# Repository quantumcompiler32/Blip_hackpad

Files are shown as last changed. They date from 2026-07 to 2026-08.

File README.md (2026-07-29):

# Blip

Blip is a custom macropad I am designing for macOS. It combines a 4-row by
3-column mechanical-key matrix, two rotary encoders, a XIAO ESP32-S3, and two
displays. The goal is to make a small physical control surface that can trigger
useful actions and show status without feeling like a tiny touchscreen.

## Features

- 12-key (3x4) mechanical switch matrix
- 1N4148 diode matrix for anti-ghosting
- Seeed Studio XIAO ESP32-S3 controller for native USB HID
- MCP23017 I2C GPIO expander for additional IO
- Newhaven 20x4 character OLED display
- Two rotary encoders with push switches
- USB-C-only power through the removable XIAO module
- A removable MCP23017 GPIO expander and removable display connections

## Bill of materials

The full, quoted CSV is in [`BOM/Hackpad_final_BOM.csv`](./BOM/Hackpad_final_BOM.csv).
It matches the current PCB: 12 keys, 12 diodes, two encoders, two 4.7 kΩ
pull-ups, one 100 nF capacitor, the XIAO ESP32-S3, the MCP23017, and both
display modules. The removable socket and header parts are listed separately
because they are assembly parts rather than separate KiCad footprints.

The current component total is **$97.95 USD** using the listed prices. That
number does not include PCB fabrication, an enclosure, keycaps, encoder knobs,
or mounting hardware. Prices are planning numbers, not a final purchase quote.

## Repository Structure

```text
Blip_hackpad/
├── BOM/                Bill of materials
├── Images/             Schematic and PCB reference images
├── PCB/                KiCad design files and manufacturing outputs
├── docs/               Architecture, specifications, and validation evidence
├── src/
│   ├── blip-agent/     Background host event pipeline
│   ├── control-center/ Minimal diagnostic view
│   ├── firmware/       Complete PlatformIO project
│   ├── shared/         Device-event and semantic-state contracts
│   └── simulator/      Virtual Blip Device and scenario CLI
└── test/               Foundation acceptance tests
```

## Hardware submission status

The KiCad project in `PCB/` is the hardware source of truth. Automated ERC,
DRC, schematic-parity, source-policy, and BOM checks are recorded in
`docs/hardware/`. The Hardware Validation Gate is not a manufacturing approval:
I still need to inspect the current STEP export, confirm connector and encoder
clearances with the real parts, review USB-C access, and sign the final
manufacturing checklist in [`docs/hardware/hardware-change-guide.md`](./docs/hardware/hardware-change-guide.md).
The complete repository-versus-Macondo checklist is in
[`docs/hardware/macondo-submission-checklist.md`](./docs/hardware/macondo-submission-checklist.md).

To rerun the repository checks:

```sh
sh scripts/verify-hardware-source-of-truth.sh
sh scripts/verify-minimal-pcb-corrections.sh
sh scripts/verify-bom-against-pcb.sh
sh scripts/verify-hardware-validation-gate.sh
```

## Simulator tracer scenario

Node.js 22.6 or newer can run the Foundation tracer without installing
dependencies:

```sh
npm test
npm run --silent scenario
npm run --silent scenario:view > /tmp/blip-control-center-diagnostic.html
```

The scenario command emits machine-readable JSON. The HTML command renders the
same Agent observation as a minimal Control Center diagnostic view. Both outputs
label the device as virtual, and the scenario never executes a host action.

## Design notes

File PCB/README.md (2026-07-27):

# Blip PCB source of truth

The three `Hackpad.kicad_*` files in this directory are the authoritative revision-one KiCad project. They were migrated unchanged from Moksh's active project on 2026-07-18.

Do not commit KiCad locks, automatic backups, local preferences, history folders, cached footprint data, or the unrelated Starter project. Hardware corrections must be made to these sources and documented in the Hardware Change Guide.

Run `sh scripts/verify-hardware-source-of-truth.sh` to verify the durable source policy. The migration hashes are historical evidence in the baseline findings; they are intentionally not enforced after approved PCB edits. A passing source-policy check does not mean the Hardware Validation Gate has passed.

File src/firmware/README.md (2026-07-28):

# Blip firmware

This folder is a self-contained PlatformIO project under the repository's
authoritative `src/` source root. Firmware files are in this project's `src/`,
headers are in `include/`, and the build configuration is `platformio.ini`.

## Controls

- Left/volume encoder: rotate for volume, press for mute.
- Right/profile encoder: rotate through three profiles, press to save/select.
- The macropad communicates and receives configuration only through USB.

Key actions and profile names are saved in ESP32 flash and can be changed over
USB serial without rebuilding the firmware. Wi-Fi and Bluetooth are disabled.

## Build and flash

1. Install [Visual Studio Code](https://code.visualstudio.com/) and the
   PlatformIO extension.
2. Open the repository's `src/firmware` folder as the PlatformIO project.
3. Connect the XIAO ESP32-S3 by USB.
4. Run **PlatformIO: Upload**.
5. Open the serial monitor at 115200 baud for diagnostics.

Command-line users can run:

```sh
cd src/firmware
pio run
pio run --target upload
pio device monitor
```

## Hardware requirements and limitations

- Newhaven pin 16 (`/RES`) must be pulled up to 3.3 V. The current schematic
  ties it to ground, which permanently resets the display.
- Newhaven pin 4 (`SA0`) must be tied to 3.3 V, selecting address `0x3D`.
  The 128x64 module remains at `0x3C`. Two devices at the same I2C address
  cannot be separated by firmware or by automatic address detection.
- This firmware requires a XIAO ESP32-S3 for native USB HID support.

## Serial commands

- `status` — rerun the I2C and peripheral report
- `config` — print the stored JSON configuration
- `set-config <JSON>` — validate and save a complete configuration
- `reset-config` — restore the example profiles
- `reboot` — restart the controller

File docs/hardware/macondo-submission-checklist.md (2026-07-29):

# Macondo submission checklist

This is the checklist I use before submitting Blip to Macondo. It separates the
repository work from the parts that need my own hands, photos, and decisions.

## Repository package

- [x] `PCB/` contains the authoritative KiCad project: schematic, board, and project file.
- [x] `BOM/Hackpad_final_BOM.csv` is valid CSV and matches the populated PCB references and footprint counts.
- [x] `src/firmware/` contains the PlatformIO firmware project.
- [x] `src/` contains the simulator and the shared device-event boundary.
- [x] `CAD/Blip-PCB-Assembly.step` is included as mechanical evidence.
- [x] `docs/hardware/` contains the pin-map contract, hardware-change guide, validation reports, and research notes.
- [x] The root README explains what Blip is, how the repository is organized, how to run the simulator, and what the current hardware status means.
- [x] The repository checks pass locally.

Run these from the repository root:

```sh
sh scripts/verify-hardware-source-of-truth.sh
sh scripts/verify-minimal-pcb-corrections.sh
sh scripts/verify-bom-against-pcb.sh
sh scripts/verify-hardware-validation-gate.sh
npm test
```

## Before I submit the hardware design for review

- [ ] Commit the final README, BOM, and verification-script changes.
- [ ] Push the commit to `main` and open the GitHub repository link in a private browser window.
- [ ] Open the KiCad project from a clean clone and confirm the schematic and PCB load without missing libraries.
- [ ] Open the current STEP export and check the board outline, mounting holes, USB-C access, display clearance, and encoder clearance.
- [ ] Confirm that the listed parts and prices still match the parts I intend to order.
- [ ] Make sure the Macondo project title and description describe the current two-display design, not an older one-screen version.

## Before I call the hardware project shipped

- [ ] Order or otherwise obtain the parts.
- [ ] Assemble the board or first article and take clear photos of the real hardware.
- [ ] Test the USB-C connection, matrix, both encoders, both displays, and the controller.
- [ ] Add honest journal entries on the Macondo project page with my own notes, photos, and what went wrong or changed.
- [ ] Complete and sign the final manufacturing checklist in `hardware-change-guide.md`.

The automated checks prove that the repository is internally consistent. They do
not prove that a real part fits, that the board has been manufactured, or that a
physical control feels right. Those are my checks to complete and document.

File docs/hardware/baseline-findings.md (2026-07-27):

# Hardware baseline findings

Recorded 2026-07-18. The Hardware Validation Gate has **not passed**. This is a preservation audit, not manufacturing approval.

## Preserved sources

| File | SHA-256 |
| --- | --- |
| `Hackpad.kicad_pro` | `d8c1aa42e53af8127d99fc2cb34fe868f9aad859bb383313cd3f733fd328e3e2` |
| `Hackpad.kicad_sch` | `2a603a45c626644701ca69ce53ecbd3906184bcae56ee97f0529a81a8c31a7d6` |
| `Hackpad.kicad_pcb` | `38016ccee050912f7b6a07835543e346bc84e0e7174babc7ce56f270c00cc676` |

The hashes match Moksh's active external project at migration time, proving that ticket 01 did not alter placement, routing, or matrix topology. They are immutable migration evidence, not a permanent test of the editable authoritative sources.

## Baseline observations

- Controller mismatch: the schematic embeds `XIAO_RP2040:MOUDLE-SEEEDUINO-XIAO`, exposes SAMD-style `PA...` pin names, and assigns `RF_Module:MCU_Seeed_ESP32C3`. The BOM and firmware require XIAO ESP32-S3. Ticket 02 must replace and verify this identity without moving the header pads.
- ERC evidence supplied before migration showed zero errors and three warnings: GND/VSS aliasing on the Newhaven display, missing XIAO symbol library, and an unattached no-connect flag. Four tests were ignored. Each warning and exclusion still needs resolution or justification.
- DRC evidence supplied before migration showed zero violations and zero unconnected items, but schematic parity was not run and five tests were ignored. A green DRC screenshot alone is not a gate pass.
- The board preserves the 4×3 matrix, two encoders, MCP23017, two I2C displays, and USB-powered XIAO header arrangement expected by the product contract.
- BOM controller text says XIAO ESP32-S3 but lists an ESP32-C3 footprint. Socket/header items and mechanical installed heights still require audit.
- KiCad CLI is not available in the current shell, so ERC, DRC, parity, and fresh mechanical export were not rerun in this ticket.

## Gate state

| Check | Baseline state |
| --- | --- |
| Authoritative source migration | Passed by matching hashes |
| Routed placement preservation | Passed by byte-identical PCB source |
| XIAO ESP32-S3 identity | Failed; correction required |
| Firmware/header-position agreement | Passed against Seeed's official D0–D10 to GPIO map |
| ERC | Not passed; warnings/exclusions open |
| DRC | Not passed for the gate; prior clean result has exclusions |
| Schematic-to-PCB parity | Not run |
| BOM/socket consistency | Not passed |
| Current budget and pull-up calculation | Not performed |
| Mechanical review and fresh STEP | Not performed |
| Human manufacturing approval | Not granted |

Ticket 02 applied the smallest evidence-backed controller, socket, power, and Newhaven I2C corrections while preserving the matrix, component placement, and existing routed nets. U1's two rows moved inward 0.88 mm to match Seeed's official 15.24 mm spacing. The baseline hashes above remain migration evidence only. Fresh DRC/parity, mechanical review, and human approval remain ticket-03 gate work.

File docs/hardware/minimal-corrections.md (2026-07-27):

# Ticket 02 minimal hardware corrections

Applied 2026-07-18. This records edits, not manufacturing approval. Primary-source electrical evidence is in [component research](component-research.md).

## Controller and assembly

- U1 now identifies only the Seeed Studio XIAO ESP32-S3 in the schematic, PCB, BOM, and firmware-facing pin contract.
- U1 now uses Seeed's official seven-by-two center pattern: 2.54 mm contact pitch and 15.24 mm row spacing, rotated into the existing board orientation. Correcting the old 17.0 mm spacing moved each row inward 0.88 mm. The existing route endpoints remain inside the 2.2 mm carrier pads, so no functional net or matrix route needed to move.
- The obsolete ESP32-C3 underside land pattern and 3D-model reference were removed. U1 5V/VBUS remains intentionally unconnected; the XIAO USB-C connector is the only power input.
- The BOM now includes exact XIAO male/female header parts, an exact 0.3-inch MCP23017 DIP socket, and exact Samtec male/female 2.54 mm connector pairs for both displays. Installed-height, enclosure, and hand-access validation remain part of the ticket-03 mechanical review.

## Newhaven display

The Newhaven NHD-0420CW-AB3 is corrected to the manufacturer's 3.3 V I2C wiring:

| Pins | Applied net | Reason |
| --- | --- | --- |
| 1, 3, 5, 6, 10–15, 17, 19, 20 | GND | VSS, REGVDD, I2C-mode NC, and BS0/BS2 requirements |
| 2, 4, 18 | 3.3 V | VDD, SA0 high, and BS1 high |
| 7 | SCL | Shared I2C clock |
| 8–9 | SDA | Required tied SDAIN/SDAOUT |
| 16 | Direct 3.3 V | Active-low reset held inactive; removes the baseline R3 part that had no PCB footprint |

SA0 high selects seven-bit address `0x3D`, leaving the fixed graphical module at `0x3C` and MCP23017 at `0x20`. New display straps use short B.Cu segments beside the existing header row; no matrix trace, switch, encoder, or component origin moved. The only U1 geometry change is the documented 0.88 mm inward movement of each header row.

## Power, pull-ups, and decoupling

- Seeed documents up to 700 mA from 3V3. The researched **external-load subtotal** is 170.8 mA. It excludes the XIAO's CPU/radio peak, regulator thermal behavior, and USB source/cable, so the worst-case current-budget criterion remains open for ticket 03.
- R1/R2 remain 4.7 kΩ. The exact graphical module has onboard 4.7 kΩ pull-ups, producing about 2.35 kΩ effective resistance and about 1.4 mA sink per low bus line. Keeping carrier pull-ups avoids making repairability depend on the graphical module.
- C1 is the existing 100 nF local rail bypass beside the MCP23017/controller area. Both display assemblies are manufacturer modules rather than bare OLED panels. No speculative bulk capacitor or display-module redesign was added; maximum-brightness, Wi-Fi, rail-noise, and I2C-rise-time measurements remain required at the Hardware Validation Gate.

## Verification still required

KiCad 10.0.1 is installed inside the macOS app bundle. Ticket-02 verification produced:

- ERC: 0 errors and 0 warnings; four project checks remain intentionally ignored and require ticket-03 disposition.
- PCB Editor DRC before the final official XIAO row-spacing correction showed 0 violations and 0 unconnected items; five checks remained ignored. The post-correction CLI DRC still aborts with exit 134, so a fresh GUI DRC is explicitly required by ticket 03.
- Schematic parity: not passed. KiCad continued to retain a stale `Missing footprint R3` marker after R3 was removed in favor of direct reset-high wiring, and the CLI DRC process aborted with exit 134 before writing a report. Ticket 03 must clear/rebuild the project cache and rerun parity from a fresh session.

Ticket 03 must also inspect the new B.Cu display straps, verify pin-one/USB/display orientation and installed heights, export a fresh STEP model, and capture the human visual approval. Do not manufacture from ticket 02 alone.

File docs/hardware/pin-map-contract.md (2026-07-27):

# Blip revision-one pin-map contract

Status: **ticket-02 electrical contract applied; fresh KiCad gate verification remains required**.

The required Blip Controller is the Seeed Studio XIAO ESP32-S3. Header-to-GPIO identities come from Seeed Studio's official XIAO ESP32-S3 pin map: <https://wiki.seeedstudio.com/xiao_esp32s3_getting_started/>. Ticket 02 replaced the obsolete controller identities with an embedded ESP32-S3 symbol and a 14-contact, 2.54 mm through-hole socket footprint. The official 15.24 mm row spacing moved each baseline row inward 0.88 mm; functional nets and their route endpoints were preserved.

| XIAO header | ESP32-S3 GPIO | Board net | Blip role | Contract state |
| --- | --- | --- | --- | --- |
| D0 | GPIO1 | `ENC_C` | Left encoder A | Agreed; later net name `LEFT_ENC_A` |
| D1 | GPIO2 | `ENC_D` | Left encoder B | Agreed; later net name `LEFT_ENC_B` |
| D2 | GPIO3 | `ENC_SW1` | Left encoder press | Agreed; later net name `LEFT_ENC_SW` |
| D3 | GPIO4 | Unconnected | Reserved | Intentionally unused; no-connect disposition remains to verify |
| D4 | GPIO5 | `SDA` | Shared I2C data | Agreed by PCB, firmware, and Seeed pin map |
| D5 | GPIO6 | `SCL` | Shared I2C clock | Agreed by PCB, firmware, and Seeed pin map |
| D6 | GPIO43 | Unconnected | Reserved UART TX | Intentionally unused |
| D7 | GPIO44 | Unconnected | Reserved UART RX | Intentionally unused |
| D8 | GPIO7 | `ENC_SW` | Right encoder press | Agreed; later net name `RIGHT_ENC_SW` |
| D9 | GPIO8 | `ENC_A` | Right encoder A | Agreed; later net name `RIGHT_ENC_A` |
| D10 | GPIO9 | `ENC_B` | Right encoder B | Agreed; later net name `RIGHT_ENC_B` |
| 3V3 | 3V3_OUT | `+3.3V` | Logic and display supply | Agreed; preliminary external maximum is 170.8 mA |
| GND | GND | `GND` | Common return | Agreed |
| 5V | VBUS | Unconnected | Not used | Required by USB-C-only power decision |

## MCP23017 matrix contract

The expander is on the shared I2C bus at `0x20`, with address pins A0–A2 grounded. GPA0–GPA3 drive `ROW0`–`ROW3`; GPB0–GPB2 read `COL0`–`COL2`. Firmware currently configures ports 0–3 as row outputs and ports 8–10 as pulled-up column inputs. The twelve switch/diode positions remain a 4×3 matrix.

## Display contract

| Component | Address | Supply | Bus role | Baseline status |
| --- | --- | --- | --- | --- |
| MCP23017 | `0x20` | 3.3 V | Matrix GPIO | A0–A2 grounded; address agrees |
| DM-OLED096-636 | `0x3C` | 3.3 V | Persistent Status | Manufacturer-default fixed address verified |
| NHD-0420CW-AB3 | `0x3D` | 3.3 V | Contextual Status | SA0 tied to 3.3 V; address agrees |

The graphical OLED connector is GND, 3.3 V, SCL, SDA on pins 1–4. Its module includes 4.7 kΩ pull-ups; together with R1/R2 this gives about 2.35 kΩ effective pull-up resistance. The Newhaven now connects VSS pins 1/20 to GND, VDD pin 2 to 3.3 V, REGVDD pin 3 to GND, SA0 pin 4 to 3.3 V, I2C NC pins 5–6 and 10–15 to GND, pin 7 to SCL, pins 8/9 together to SDA, /RES pin 16 directly to 3.3 V, BS0/BS2 pins 17/19 to GND, and BS1 pin 18 to 3.3 V. This selects 3.3 V I2C operation and address `0x3D`. Direct reset-high replaced the baseline R3 pull-up because R3 had no PCB footprint and no controlled reset is required.

The preliminary maximum external 3.3 V load is 170.8 mA: 135 mA Newhaven, 32 mA graphical OLED, 1 mA MCP23017, and 2.8 mA with both I2C lines low through the effective pull-ups. See [component research](component-research.md) for primary sources and limitations. The 700 mA Seeed regulator-output statement leaves nominal margin, but radio/CPU peaks, thermal behavior, bus rise time, display brightness, and assembled measurements remain Hardware Validation Gate checks.

USB-C on the XIAO is the only power input and carries USB HID plus serial. No project path, secret, or host configuration crosses this hardware contract.

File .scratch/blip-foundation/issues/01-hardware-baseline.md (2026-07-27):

# 01 — Establish the authoritative Blip hardware baseline

**What to build:** Preserve the active KiCad project as Blip's single hardware source of truth and produce one reviewed XIAO ESP32-S3 pin-map contract covering every hardware and firmware connection.

**Blocked by:** None — can start immediately.

**Status:** ready-for-agent

- [ ] Only the active KiCad sources are authoritative; generated history, locks, preferences, and unrelated projects are excluded.
- [ ] Existing placement, routing, and matrix topology are preserved.
- [ ] One pin-map contract records the agreed controller target and every observed agreement or mismatch across inputs, displays, I2C, USB, power, firmware, and KiCad.
- [ ] Baseline ERC, DRC, parity, BOM, and mechanical findings are recorded without claiming the gate passed.

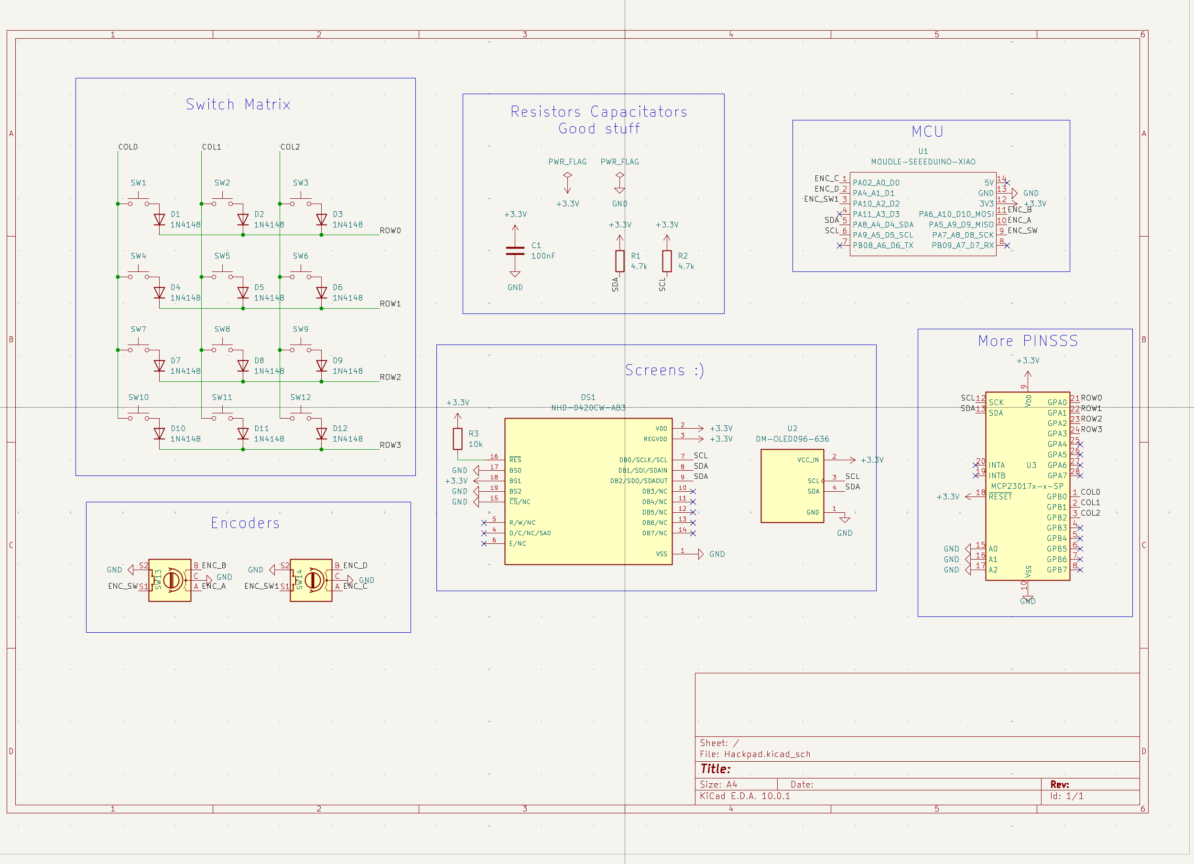
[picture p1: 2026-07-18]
Images/PCBSchematic.png

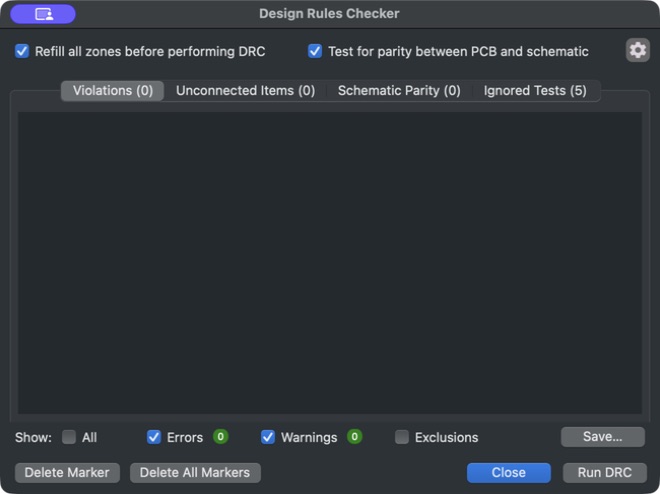
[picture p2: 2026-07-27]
docs/hardware/evidence/drc-parity.png

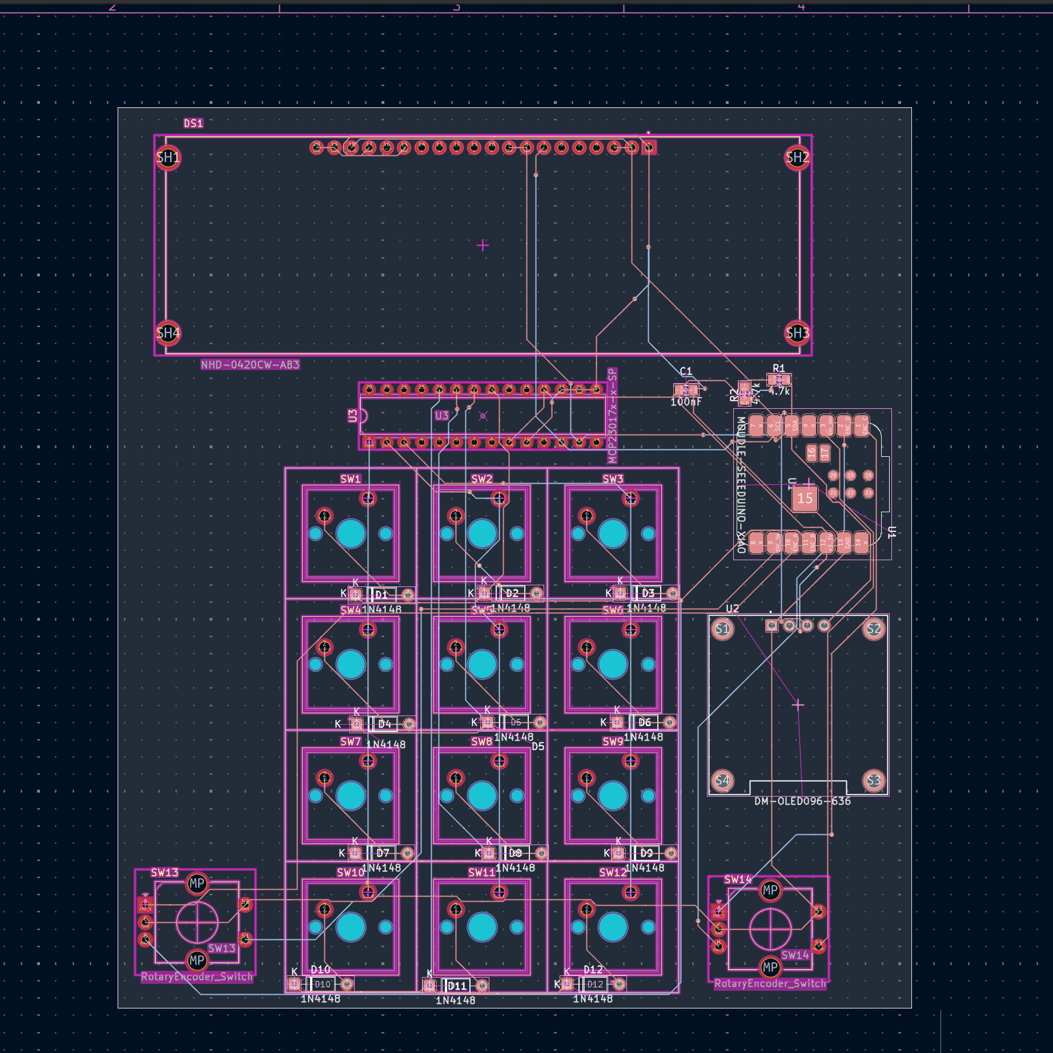
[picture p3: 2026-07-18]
Images/PCBFront.png

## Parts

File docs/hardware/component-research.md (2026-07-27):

# Component research for minimal PCB corrections

This note records only first-party manufacturer facts needed by ticket 02. It is not a substitute for a fresh ERC, DRC, schematic/PCB parity check, assembled-board test, or human manufacturing approval.

## Decision summary

| Part | Evidence-backed ticket 02 constraint |
| --- | --- |
| Seeed Studio XIAO ESP32-S3 | Use the official XIAO ESP32-S3 symbol/footprint and its 14 castellated/header pins. D4/GPIO5 is SDA, D5/GPIO6 is SCL, and 3V3 is a regulated output rated by Seeed for 700 mA. Keep 5V/VBUS unconnected on the carrier for the locked USB-C-only design. |
| Newhaven NHD-0420CW-AB3 | In I2C mode it is 3.3 V only: VDD=3.3 V and REGVDD=0 V. Tie SDAIN and SDAOUT together, set BS0=0, BS1=1, BS2=0, and use SA0 high to select 7-bit address `0x3D`. |
| DisplayModule DM-OLED096-636 | The four-pin breakout is GND, VCC_IN, SCL, SDA and accepts 2.8–5.5 V at VCC_IN. Its documented default control byte `0x78` is 7-bit address `0x3C`. The module schematic already includes 4.7 kΩ I2C pull-ups. |
| Microchip MCP23017 | Operates from 1.8–5.5 V, draws at most 1 mA under the specified 1 MHz condition, and uses 7-bit address `0100 A2 A1 A0`; biasing A2:A0 low selects `0x20`. A0:A2 and RESET must not float. |

## Seeed Studio XIAO ESP32-S3

- The standard board is **21 mm × 17.8 mm**. Seeed publishes the authoritative DXF, KiCad project, symbol library, footprint library, and 3D model from the product wiki. The PCB should import/use those official assets instead of retaining the current ESP32-C3 footprint or the SAMD-style symbol. [Seeed XIAO ESP32-S3 hardware overview and resources](https://wiki.seeedstudio.com/xiao_esp32s3_getting_started/)
- The official header mapping relevant to Blip is: D0=GPIO1, D1=GPIO2, D2=GPIO3, D4/SDA=GPIO5, D5/SCL=GPIO6, D8=GPIO7, D9=GPIO8, and D10=GPIO9. The same page identifies 5V as VBUS, 3V3 as `3V3_OUT`, and GND as ground. [Seeed pin map](https://wiki.seeedstudio.com/xiao_esp32s3_getting_started/#xiao-esp32-s3-front)
- Seeed describes the 3V3 pin as the onboard regulator's output and says **700 mA may be drawn**. It describes the 5V pin as USB-port output and warns that external input on that pin requires a diode. Blip does not use external 5V injection, so the carrier's 5V/VBUS header pin should remain unconnected. [Seeed power-pin guidance](https://wiki.seeedstudio.com/xiao_esp32s3_getting_started/#power-pins)
- Seeed lists typical standard-board consumption as **5 V at 19 mA** during its unspecified baseline operating condition. This is not a radio-transmit peak and must not be used as a worst-case ESP32-S3 current figure. [Seeed specifications](https://wiki.seeedstudio.com/xiao_esp32s3_getting_started/#specification)
- The module is supplied without headers by default; Seeed instructs the user to solder headers for expansion-board use. A socketed Blip assembly therefore requires explicit matching 2.54 mm header/socket BOM items rather than assuming they ship with the XIAO. [Seeed solder-header guidance](https://wiki.seeedstudio.com/xiao_esp32s3_getting_started/#solder-header)
- Seeed's official `XIAO-ESP32-S3-DIP.kicad_mod` places the two through-hole header rows at `y=-7.62 mm` and `y=+7.62 mm`, for **15.24 mm row spacing**, and places seven contacts per row at 2.54 mm pitch. Blip rotates that exact center pattern 90 degrees to suit the existing board orientation. [Seeed official XIAO ESP32-S3 DIP footprint](https://github.com/Seeed-Studio/OPL_Kicad_Library/blob/master/Seeed%20Studio%20XIAO%20Series%20Library/XIAO-ESP32-S3-DIP.kicad_mod)

### XIAO remaining uncertainty

- The wiki's 700 mA statement is a regulator-output claim, but it does not give a complete thermal derating curve or a worst-case Wi-Fi/BLE current budget for the assembled Blip. It is suitable as an upper regulator limit, not proof that any arbitrary 700 mA peripheral load is safe.
- Header centers are now derived from Seeed's official footprint. USB-C, antenna, reset/boot, socket body, and enclosure clearances still require the ticket-03 2D/3D and physical-fit gate.

## Newhaven NHD-0420CW-AB3

The following facts come from revision 5 of Newhaven's official product specification. [NHD-0420CW-AB3 product specification](https://newhavendisplay.com/content/specs/NHD-0420CW-AB3.pdf)

### Required 3.3 V I2C wiring

| Pin | Signal | Required connection |
| ---: | --- | --- |
| 1 | VSS | GND |
| 2 | VDD | 3.3 V |
| 3 | REGVDD | GND; the datasheet requires 0 V for 3.3 V operation |
| 4 | SA0 | 3.3 V for 7-bit address `0x3D` |
| 5–6 | NC | GND, per datasheet |
| 7 | SCL | Shared I2C SCL |
| 8 | SDAIN | Shared I2C SDA |
| 9 | SDAOUT | Tie to pin 8 and shared I2C SDA |
| 10–15 | NC | GND, per datasheet |
| 16 | /RES | Active-low reset; a pull-up is acceptable if no MCU reset control is required |
| 17 | BS0 | GND (`0`) |
| 18 | BS1 | 3.3 V (`1`) |
| 19 | BS2 | GND (`0`) |
| 20 | VSS | GND |

Newhaven explicitly says I2C operation supports **3.3 V only**, with VDD=3.3 V and REGVDD=0 V; 5 V I2C mode is not supported. Its interface table selects I2C with BS0/BS1/BS2=`0/1/0`. The I2C pin-assignment summary uses SA0 as the address-select signal and requires SDAIN/SDAOUT to be tied together. [NHD-0420CW-AB3 product specification, pp. 4–5](https://newhavendisplay.com/content/specs/NHD-0420CW-AB3.pdf)

The module specification does not print the resulting hexadecimal addresses in its pin table, but Newhaven's official US2066 controller specification gives the 7-bit address as `0111100` or `0111101`, with SA0 as the low address bit. Therefore SA0 low is `0x3C` and SA0 high is `0x3D`. [Newhaven-hosted US2066 specification, section 5.1.4](https://newhavendisplay.com/content/app_notes/US2066.pdf)

### Current and logic levels

- VDD is specified as 2.7–3.6 V for nominal 3.3 V operation.
- Supply current is **70 mA typical, 135 mA maximum**; sleep current is 2 mA typical, 5 mA maximum.
- Input-high is at least 0.8×VDD and input-low is at most 0.2×VDD, so a 3.3 V XIAO and 3.3 V pull-ups are level-compatible.

## DisplayModule DM-OLED096-636

The manufacturer hosts both a product page and the official 2018 datasheet. [DisplayModule product page](https://www.displaymodule.com/products/0-96-inch-oled-graphic-display-128x64-with-i2c) [DM-OLED096-636 datasheet](https://cdn.shopify.com/s/files/1/0264/7629/files/DM-OLED096-636_Datasheet.pdf?v=1659336245)

- The breakout connector is pin 1 GND, pin 2 VCC_IN (**2.8–5.5 V**), pin 3 SCL, and pin 4 SDA. Feeding VCC_IN from Blip's 3.3 V rail is within the module specification.
- The module is a 128×64 I2C display using an SSD1315 controller and measures 26.0 × 26.0 × 2.7 mm.
- Operating current is **25 mA typical, 32 mA maximum** under the datasheet's stated condition (VDD=2.8 V, internally generated VCC=7.25 V, 100% display area on).
- The module schematic includes **4.7 kΩ pull-ups on both SDA and SCL**. Retaining Blip's existing 4.7 kΩ bus pull-ups would place each pair in parallel for about 2.35 kΩ effective pull-up resistance while this exact module is installed.
- The datasheet calls `0x78` the default I2C "slave address" and `0x7A` the alternate when the panel D/C#/SA0 pin is high. Those values include the R/W bit: their 7-bit forms are respectively **`0x3C` and `0x3D`**. The four-pin breakout does not expose D/C#/SA0, and its module schematic documents the default `0x78`, so Blip should treat this module as fixed at 7-bit **`0x3C`**.

### DM-OLED096-636 uncertainties

- The product page says "Power Supply: 2.8 V" while the module-connector table says VCC_IN accepts 2.8–5.5 V. The connector table and module schematic are the more specific breakout-level evidence; 3.3 V is inside both the controller logic maximum and the VCC_IN range.
- The 4-pin module cannot be field-strapped to `0x3D` without modifying its internal panel wiring. The Newhaven display should therefore take `0x3D`.

## Microchip MCP23017

The following facts come from Microchip's current DS20001952D datasheet. [MCP23017/MCP23S17 datasheet](https://ww1.microchip.com/downloads/aemDocuments/documents/APID/ProductDocuments/DataSheets/MCP23017-Data-Sheet-DS20001952.pdf)

- Supply range is 1.8–5.5 V. Maximum supply current is **1 mA** at the datasheet's SCL=1 MHz test condition; standby current is at most 1 µA through +85 °C.
- The I2C address bits are `0100 A2 A1 A0`. Biasing A2, A1, and A0 low yields 7-bit address **`0x20`**. Microchip says all three address pins must be externally biased.
- RESET must also be externally biased; it must not float. The existing direct 3.3 V connection is a valid always-enabled choice if no controlled reset is required.
- At 3.3 V, 100 kHz and 400 kHz I2C modes are supported. The datasheet permits up to 400 pF bus capacitance at those speeds and specifies maximum rise times of 1000 ns at 100 kHz and 300 ns at 400 kHz. Pull-up selection must ultimately be checked against the assembled bus capacitance, not chosen from resistance alone.
- MCP23017's optional GPIO pull-ups are approximately 100 kΩ and apply to GPIO inputs, not SDA/SCL. They can pull up the three matrix column inputs in firmware, but they do not replace the external I2C pull-ups.

## Preliminary 3.3 V current budget

This is a conservative component subtotal, not a passed power-validation gate:

| Load | Maximum used |
| --- | ---: |
| Newhaven NHD-0420CW-AB3 | 135 mA |
| DM-OLED096-636 | 32 mA |
| MCP23017 core | 1 mA |
| Two I2C lines low through effective 2.35 kΩ pull-ups | 2.8 mA |
| **External subtotal** | **170.8 mA** |

This subtotal is below Seeed's stated 700 mA 3V3-output figure, but the remaining margin cannot be called validated until the XIAO ESP32-S3's own worst-case radio/CPU draw, regulator thermal behavior, actual display brightness patterns, and the connected USB source/cable are included and measured. A conservative firmware validation should test both displays at maximum intended brightness while Wi-Fi transmits.

## Minimal-change implications

1. Replace only U1's incorrect symbol/footprint/BOM identity with the XIAO ESP32-S3 contract. Use Seeed's official 2.54 mm pitch and 15.24 mm row spacing, rotated into Blip's existing orientation; preserve named functional nets and placement where possible.
2. Leave XIAO 5V/VBUS unconnected and power peripherals from 3V3.
3. Correct the Newhaven wiring: REGVDD to GND, SA0 to 3V3, BS0/BS2 to GND, BS1 to 3V3, all datasheet-designated I2C NC pins to GND, SDAIN+SDAOUT together, and /RES held high.
4. Keep the graphical module at 7-bit `0x3C`; use the Newhaven at `0x3D`; keep MCP23017 at `0x20`.
5. Existing 4.7 kΩ board pull-ups plus the graphical module's onboard 4.7 kΩ pull-ups produce about 2.35 kΩ effective pull-ups. This is electrically plausible at 3.3 V, but a fresh bus-capacitance/rise-time check and assembled waveform measurement remain required. Removing the carrier pull-ups would make the bus dependent on this exact graphical breakout, so retaining them is the more repairable minimal-change baseline unless measurement shows excessive sink current.

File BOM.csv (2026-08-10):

Name | Purpose | Quantity | Unit Cost (USD) | Total Cost (USD) | Distributor | Manufacturer | Manufacturer Part Number | PCB/Schematic References | PCB Footprint | Purchase Link | Assembly Scope | Fit / Notes
Seeed Studio XIAO ESP32-S3 | USB HID controller, serial transport, and 3.3 V supply | 1 | 7.49 | 7.49 | DigiKey | Seeed Studio | 113991114 | U1 | Blip:XIAO_ESP32S3_Socket | https://www.digikey.com/en/products/detail/seeed-technology-co-ltd/113991114/17847787 | PCB-fitted | Install in two 7-position 2.54 mm female sockets. USB-C faces the board edge marked USB-C ACCESS.
XIAO 7-position female socket header | Removable PCB socket for the XIAO ESP32-S3 | 2 | 1.36 | 2.72 | DigiKey | Samtec | SSW-107-01-T-S | U1 socket | Blip:XIAO_ESP32S3_Socket | https://www.digikey.com/en/products/detail/samtec-inc/SSW-107-01-T-S/1111321 | PCB assembly | Two single-row sockets are required; verify pin 1 and installed height before manufacture.
XIAO 7-position male header | Headers soldered to the removable XIAO ESP32-S3 | 2 | 0.63 | 1.26 | DigiKey | Samtec | TSW-107-07-T-S | U1 module header | Blip:XIAO_ESP32S3_Socket | https://www.digikey.com/en/products/detail/samtec-inc/TSW-107-07-T-S/1101256 | Module assembly | Two single-row headers mate with the PCB sockets; the XIAO module is supplied without these headers.
Newhaven 20x4 Character OLED Display | Contextual Status display | 1 | 36.27 | 36.27 | DigiKey | Newhaven Display International | NHD-0420CW-AB3 | DS1 | NHD-0420CW-AB3:LCD_NHD-0420CW-AB3 | https://www.digikey.com/en/products/detail/newhaven-display-intl/NHD-0420CW-AB3/5022951 | PCB assembly | Exact 20-pin display and matching custom footprint.
Newhaven 20-position female socket header | Removable PCB socket for the character display | 1 | 3.93 | 3.93 | DigiKey | Samtec | SSW-120-01-T-S | DS1 socket | NHD-0420CW-AB3:LCD_NHD-0420CW-AB3 | https://www.digikey.com/en/products/detail/samtec-inc/SSW-120-01-T-S/1111372 | PCB assembly | One 20-position 2.54 mm socket; verify pin 1, installed height, and display clearance.
Newhaven 20-position male header | Header soldered to the character display | 1 | 1.63 | 1.63 | DigiKey | Samtec | TSW-120-07-T-S | DS1 module header | NHD-0420CW-AB3:LCD_NHD-0420CW-AB3 | https://www.digikey.com/en/products/detail/samtec-inc/TSW-120-07-T-S/1101300 | Module assembly | One 20-position 2.54 mm header mates with the PCB socket.
0.96-inch 128x64 I2C OLED Module | Persistent Status display | 1 | 4.90 | 4.90 | DisplayModule | DisplayModule | DM-OLED096-636 | U2 | DM-OLED096-636:MODULE_DM-OLED096-636 | https://www.displaymodule.com/products/0-96-inch-oled-graphic-display-128x64-with-i2c | PCB assembly | Use the 26 mm x 26 mm I2C module matching the listed custom footprint.
Graphical OLED 4-position female socket header | Removable PCB socket for the graphical display | 1 | 1.07 | 1.07 | DigiKey | Samtec | SSW-104-01-T-S | U2 socket | DM-OLED096-636:MODULE_DM-OLED096-636 | https://www.digikey.com/en/products/detail/samtec-inc/SSW-104-01-T-S/1111318 | PCB assembly | One 4-position 2.54 mm socket; verify GND pin 1 and installed height.
Graphical OLED 4-position male header | Header soldered to the graphical display | 1 | 0.55 | 0.55 | DigiKey | Samtec | TSW-104-07-T-S | U2 module header | DM-OLED096-636:MODULE_DM-OLED096-636 | https://www.digikey.com/en/products/detail/samtec-inc/TSW-104-07-T-S/1101247 | Module assembly | One 4-position 2.54 mm header mates with the PCB socket.
MCP23017 16-bit I2C GPIO expander | Drives the 4-row by 3-column switch matrix | 1 | 1.69 | 1.69 | DigiKey | Microchip Technology | MCP23017-E/SP | U3 | Package_DIP:DIP-28_W7.62mm | https://www.digikey.com/en/products/detail/microchip-technology/MCP23017-E-SP/894272 | PCB-fitted | Use the SPDIP-28 package shown by the PCB footprint. Do not substitute SOIC or SSOP.
28-pin 0.3-inch DIP socket | Removable socket for the MCP23017 | 1 | 3.93 | 3.93 | DigiKey | Mill-Max | 110-44-628-41-001000 | U3 socket | Package_DIP:DIP-28_W7.62mm | https://www.digikey.com/en/products/detail/mill-max-manufacturing-corp/110-44-628-41-001000/947071 | PCB assembly | Align the socket notch and MCP23017 pin 1 with the U3 marking.
Alps Alpine EC11E rotary encoder with push switch | Two rotary inputs for Blip controls | 2 | 5.00 | 10.00 | DigiKey | Alps Alpine | EC11E09244AQ | SW13, SW14 | Rotary_Encoder:RotaryEncoder_Alps_EC11E-Switch_Vertical_H20mm_CircularMountingHoles | https://www.digikey.com/en/products/detail/alps-alpine/EC11E09244AQ/21721552 | PCB-fitted | Both encoder footprints use the same 20 mm vertical EC11E pattern. Confirm shaft, detent, mounting-tab, and knob clearance.
Cherry MX PCB-mount mechanical keyswitch | Twelve switches in the 4-row by 3-column matrix | 12 | 1.75 | 21.00 | DigiKey | Cherry Americas | MX2A-E1NW | SW1-SW12 | Button_Switch_Keyboard:SW_Cherry_MX_1.00u_PCB | https://www.digikey.com/en/products/detail/cherry-americas-llc/MX2A-E1NW/21738396 | PCB-fitted | Through-hole Cherry MX 1.00u footprint. Keycaps are not included.
1N4148 through-hole switching diode | Prevents ghosting in the switch matrix | 12 | 0.10 | 1.20 | DigiKey | onsemi | 1N4148 | D1-D12 | Diode_THT:D_DO-35_SOD27_P7.62mm_Horizontal | https://www.digikey.com/en/products/detail/onsemi/1N4148/458603 | PCB-fitted | Twelve axial DO-35 diodes, one per switch position.
4.7 kOhm 1% 0805 resistor | I2C pull-ups on the shared bus | 2 | 0.10 | 0.20 | DigiKey | YAGEO | RC0805FR-074K7L | R1, R2 | Resistor_SMD:R_0805_2012Metric_Pad1.20x1.40mm_HandSolder | https://www.digikey.com/en/products/detail/yageo/RC0805FR-074K7L/727929 | PCB-fitted | Two hand-solder 0805 resistors. The graphical OLED module also contains its own pull-ups; the combined bus strength is documented separately.
100 nF 50 V X7R 0805 ceramic capacitor | Local 3.3 V decoupling at the controller/expander rail | 1 | 0.11 | 0.11 | DigiKey | YAGEO | CC0805KRX7R9BB104 | C1 | Capacitor_SMD:C_0805_2012Metric_Pad1.18x1.45mm_HandSolder | https://www.digikey.com/en/products/detail/yageo/CC0805KRX7R9BB104/302874 | PCB-fitted | One hand-solder 0805 capacitor.

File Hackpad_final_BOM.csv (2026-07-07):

Name | Purpose | Quantity | Unit Cost (USD) | Total Cost (USD) | Distributor | Manufacturer | Manufacturer Part Number | Schematic References | PCB Footprint | Link | Fit / Notes
Seeed Studio XIAO ESP32C3 | Main microcontroller module; exact match for PCB footprint RF_Module:MCU_Seeed_ESP32C3 | 1 | 4.99 | 4.99 | DigiKey | Seeed Studio | 113991054 | U1 | RF_Module:MCU_Seeed_ESP32C3 | https://www.digikey.com/en/products/detail/seeed-technology-co-ltd/113991054/16652880 | Exact ESP32-C3 XIAO footprint used by the finalized PCB. Headers are not included and are not required if the module is soldered directly.
Newhaven 20x4 Character OLED Display | Primary 20-column by 4-line character display | 1 | 36.27 | 36.27 | DigiKey | Newhaven Display International | NHD-0420CW-AB3 | DS1 | NHD-0420CW-AB3:LCD_NHD-0420CW-AB3 | https://www.digikey.com/en/products/detail/newhaven-display-intl/NHD-0420CW-AB3/5022951 | Exact schematic part number and exact custom PCB footprint.
0.96-inch 128x64 I2C OLED Module | Secondary compact graphics display | 1 | 4.9 | 4.9 | DisplayModule | DisplayModule | DM-OLED096-636 | U2 | DM-OLED096-636:MODULE_DM-OLED096-636 | https://www.displaymodule.com/products/0-96-inch-oled-graphic-display-128x64-with-i2c | Exact schematic part number and matching custom PCB footprint. Select the standard module version matching the listed 26 x 26 mm board.
MCP23017 16-bit I2C GPIO Expander, SPDIP-28 | Expands the available GPIO pins for displays and controls | 1 | 1.69 | 1.69 | DigiKey | Microchip Technology | MCP23017-E/SP | U3 | Package_DIP:DIP-28_W7.62mm | https://www.digikey.com/en/products/detail/microchip-technology/MCP23017-E-SP/894272 | Exact 28-pin SPDIP package required by the PCB. Do not substitute SOIC or SSOP versions.
Alps Alpine EC11E Rotary Encoder with Push Switch | Rotary input controls with integrated push buttons | 2 | 5.0 | 10.0 | DigiKey | Alps Alpine | EC11E09244AQ | SW13, SW14 | Rotary_Encoder:RotaryEncoder_Alps_EC11E-Switch_Vertical_H20mm_CircularMountingHoles | https://www.digikey.com/en/products/detail/alps-alpine/EC11E09244AQ/21721552 | 20 mm vertical EC11E body with push switch and matching PCB pin pattern. Exact shaft feel/detent count does not affect PCB fit.
Cherry MX PCB-mount Mechanical Keyswitch | Twelve keys in the 3 x 4 switch matrix | 12 | 1.75 | 21.0 | DigiKey | Cherry Americas | MX2A-E1NW | SW1-SW12 | Button_Switch_Keyboard:SW_Cherry_MX_1.00u_PCB | https://www.digikey.com/en/products/detail/cherry-americas-llc/MX2A-E1NW/21738396 | Cherry MX through-hole keyswitch matching the PCB's Cherry MX 1.00u footprint. Keycaps are not included in the schematic BOM.
1N4148 Through-hole Switching Diode | Prevents ghosting in the key matrix | 12 | 0.1 | 1.2 | DigiKey | onsemi | 1N4148 | D1-D12 | Diode_THT:D_DO-35_SOD27_P7.62mm_Horizontal | https://www.digikey.com/en/products/detail/onsemi/1N4148/458603 | Exact DO-35 axial package required by the PCB's 7.62 mm horizontal footprint.
4.7 kΩ 1% 0805 Resistor | I2C pull-up resistors | 2 | 0.1 | 0.2 | DigiKey | YAGEO | RC0805FR-074K7L | R1, R2 | Resistor_SMD:R_0805_2012Metric_Pad1.20x1.40mm_HandSolder | https://www.digikey.com/en/products/detail/yageo/RC0805FR-074K7L/727929 | Exact 0805 metric package; 1% tolerance.
10 kΩ 1% 0805 Resistor | Display/control pull-up resistor | 1 | 0.1 | 0.1 | DigiKey | YAGEO | RC0805FR-0710KL | R3 | Resistor_SMD:R_0805_2012Metric_Pad1.20x1.40mm_HandSolder | https://www.digikey.com/en/products/detail/yageo/RC0805FR-0710KL/727535 | Exact 0805 metric package; 1% tolerance.
100 nF 50 V X7R 0805 Ceramic Capacitor | 3.3 V power decoupling | 1 | 0.11 | 0.11 | DigiKey | YAGEO | CC0805KRX7R9BB104 | C1 | Capacitor_SMD:C_0805_2012Metric_Pad1.18x1.45mm_HandSolder | https://www.digikey.com/en/products/detail/yageo/CC0805KRX7R9BB104/302874 | Exact 0805 metric package. 50 V rating is safely above the 3.3 V circuit voltage.

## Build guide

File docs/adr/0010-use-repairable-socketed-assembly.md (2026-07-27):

# Use repairable socketed assembly

Blip hardware revision one is hand-assembled and keeps its high-value or programmable components removable: the XIAO ESP32-S3 uses female headers, the MCP23017 uses a DIP socket, and both displays use removable headers or connectors. Switches, diodes, encoders, passives, and connectors are soldered normally. The BOM includes the exact sockets and headers, while the layout, STEP export, and Hardware Change Guide verify pin-one and connector orientation, installed height, USB-C access, mechanical clearance, left/right encoder labels, and display/I²C silkscreen markings.

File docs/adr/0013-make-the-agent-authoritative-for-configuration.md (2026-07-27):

# Make the Agent authoritative for configuration

The Blip Agent’s SQLite database is the authoritative source for Blip Configuration, while Control Center edits it through validated commands and JSON import/export serves only as portable backup and interchange. The Blip Device stores hardware settings, current profile, protocol version, and Offline Control settings, synchronizing device-relevant revisions with the Agent on connection. Integration credentials and sessions remain in macOS Keychain and are omitted from SQLite exports; service credentials, project paths, and Codex or Git configuration are never sent to firmware.

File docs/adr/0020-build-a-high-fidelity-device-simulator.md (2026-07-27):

# Build a high-fidelity device simulator

The Foundation Release includes a clearly identified virtual Blip Device that emits switch down/up and encoder rotation/press events through the same Agent-side device-event boundary as serial hardware and renders both displays from the same display-state model. It supports connection and protocol failures, stale heartbeats, incompatible firmware, optional latency and action failure injection, Test and Dry Run behavior, and a CLI for automated event tests. Simulated state never masquerades as physical-device state or stores fake external credentials.

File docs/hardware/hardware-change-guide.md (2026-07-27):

# Blip Hardware Validation Gate

Status: **AUTOMATION COMPLETE — HUMAN SIGN-OFF REQUIRED**

This is the single manufacturing-review guide for the Macondo/Stardance submission. It records the minimum changes made to the existing board, the reproducible checks, and the remaining physical decisions. Do not order the PCB until the final checklist is signed.

## Gate result

| Check | Result | Evidence / disposition |
| --- | --- | --- |
| ERC | **ERC PASS** | `evidence/erc.rpt`: 0 violations |
| Board rules | **DRC PASS** | `evidence/drc.rpt`: 0 violations |
| PCB/schematic parity | **Schematic parity PASS** | KiCad DRC run with “Test for parity” enabled: 0 |
| Connectivity | **Unconnected items PASS** | KiCad DRC: 0 unconnected pads |
| BOM and pin map | **PASS** | `scripts/verify-hardware-source-of-truth.sh` and `scripts/verify-minimal-pcb-corrections.sh` |
| Mechanical export | **PARTIAL / HUMAN GATE** | `../../CAD/Blip-PCB-Assembly.step` is fresh, but it is not a complete assembly model. KiCad could not resolve stock switch and encoder models, and the XIAO/display modules have no embedded product models. Installed heights require the checklist below. |

The five names under “Ignored checks” in `evidence/drc.rpt` are project-level disabled rule classes, not hidden marker exclusions. Their dispositions are explicit:

- **Footprint has no courtyard:** not used as manufacturing proof. U1 has a checked courtyard; all other physical envelope/height decisions remain in the unsigned mechanical checklist.
- **Track endpoint not centered on via:** legacy routing-style check only; connectivity, clearance, shorts, and unconnected-item checks remain enabled and clean.
- **Tuning profile track geometries:** Blip has no tuned high-speed pairs or tuning profiles.
- **Footprint does not match symbol filters:** library metadata check; BOM/pin identity is enforced by the source-of-truth scripts.
- **Footprint component type does not match pads:** metadata check; every fitted part/pad mapping remains covered by ERC, DRC, BOM, and pin-map verification.

There are no excluded DRC markers. If a reviewer requires these global classes enabled, that is a separate board-policy change; this gate does not imply they ran.

## What changed

```text
Before at e0d795d                    After
XIAO rows: already 15.24 mm          XIAO rows: 15.24 mm, unchanged
Header pads: 2.20 / 1.00 mm          Header pads: 1.524 / 0.889 mm
Routes relied on oversized pads      Routes terminate on official pad centers
Stale display power trace present   Stale trace removed
U1-area routing no longer aligned   Only U1/display-area tracks rerouted
DRC after official geometry: 29     DRC: 0 errors, 0 unconnected, 0 parity
```

Review the [annotated before/after composite](evidence/before-after-annotated.svg), backed by the raw [before — e0d795d](evidence/board-before-e0d795d.svg) and [after — validated](evidence/board-after.svg) exports. Callout A marks the official XIAO pad geometry, B marks the removed stale display-power segment, and C marks the localized SDA/ENC_D reroute. The git diff against `e0d795d` is the coordinate-level record; no switches, encoders, display outline, mounting holes, or board outline were recreated.

`evidence/validation-results.txt` binds both source files and exported evidence by SHA-256 so a later PCB/schematic edit makes the verifier fail instead of accepting stale reports.

## Ordered KiCad operations

1. Open `PCB/Hackpad.kicad_pro`, then open the PCB Editor.
2. Confirm U1 uses `Blip:XIAO_ESP32S3_Socket`, rotated −90°, with USB-C facing the edge labelled `USB-C ACCESS`.
3. In Footprint Properties, verify 14 through-hole pads, 2.54 mm pitch along each row, 15.24 mm between rows, 1.524 mm pad diameter, and 0.889 mm drill.
4. Preserve the existing XIAO pin order. Do not renumber pads or swap the two rows.
5. Inspect the localized U1/display reroute. The SDA bridge changes layers to avoid the SCL/power barriers; ENC_D routes below the 3.3 V via and the display mounting hole.
6. Refill zones. Open Inspect → Design Rules Checker, enable both zone refill and schematic parity, then run DRC.
7. Require 0 DRC violations, 0 unconnected items, and 0 parity differences. Do not accept a U1 library-copy warning; the library and placed footprint are synchronized.
8. In Schematic Editor, run ERC and require 0 violations.
9. Export a fresh STEP file after every footprint or outline change.

## Locked electrical mapping

| Function | XIAO signal |
| --- | --- |
| Encoder 1 A / B / push | D0 / D1 / D2 |
| I²C SDA / SCL | D4 / D5 |
| Encoder 2 push / A / B | D8 / D9 / D10 |
| Logic power | XIAO 3V3 output only |
| Board power | USB-C into XIAO only; never inject external 3.3 V |

The MCP23017 remains at address `0x20` with A0–A2 grounded. The 3×4 switch matrix remains COL0–COL2 and ROW0–ROW3 with one diode per key.

## Mechanical and manufacturing checklist

- [ ] Open the current STEP and visually confirm the PCB outline and all mounting holes.
- [ ] Fit the real XIAO/socket combination and record total installed height.
- [ ] Confirm the XIAO USB-C plug is reachable with the enclosure assembled.
- [ ] Fit both physical displays and confirm header pitch, pin 1, orientation, and clearance above the XIAO/socket.
- [ ] Fit both encoders; confirm shaft, body, mounting-tab, and knob clearance.
- [ ] Confirm encoder clockwise direction with continuity testing or first-article firmware.
- [ ] Confirm no metal display or enclosure feature contacts XIAO antenna/components.
- [ ] Review the fabrication Gerbers in the board house viewer after export.
- [ ] Measure first-article USB current before enabling both displays at full brightness.
- [ ] Confirm no external 3.3 V supply is connected while USB-C is attached.
- [ ] Moksh signs and dates the manufacturing decision below.

**HUMAN SIGN-OFF REQUIRED**

- [ ] Approved for manufacture by Moksh: __________________  Date: __________

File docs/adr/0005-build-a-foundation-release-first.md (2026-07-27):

# Build a Foundation Release first

Blip’s first milestone is a Foundation Release proving the complete device-to-Agent-to-Control-Center loop before Spotify, Telegram, Coding/Codex, Research, and Feature Forge are added as later vertical slices. It includes the bundled macOS components, serial handshake, physical and simulated input through one event pipeline, three profiles and Fixed Controls, configurable actions and persistence, Pomodoro, both display roles and animation, basic macOS actions, logs, and permission guidance. This sequences rather than removes the remaining product scope and creates a usable hardware-backed base on which integrations can be tested independently.

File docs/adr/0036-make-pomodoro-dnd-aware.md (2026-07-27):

# Make Pomodoro DND-aware

The DND setup assistant guides the user to allow Blip notifications through the selected macOS Focus mode and requests Time Sensitive notification capability where supported. Control Center tests notification and alarm behavior while that Focus is active and warns when macOS still suppresses it; the physical displays always report timer completion. Blip never bypasses system Focus controls without permission, and Focus Mode may optionally invoke its configured Shortcut to disable DND when the work session ends.

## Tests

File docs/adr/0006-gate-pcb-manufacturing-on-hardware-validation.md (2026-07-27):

# Gate PCB manufacturing on hardware validation

Blip’s PCB must not be submitted for manufacturing until its Hardware Validation Gate passes: display datasheets and addresses are verified, the Newhaven control pins have defined levels, voltages and pull-ups are correct, physical encoder identity and direction are established, KiCad ERC findings are resolved or justified, and schematic, layout, BOM, firmware pin map, and hardware documentation agree. The repository’s `PCB/` directory is the single source of truth for the active `.kicad_pro`, `.kicad_sch`, and `.kicad_pcb` files; automatic history, backups, locks, local preferences, and the unrelated Starter project are excluded. Codex may migrate, audit, and make evidence-backed corrections to those source files, then run ERC, DRC, and schematic parity. All required edits and evidence live in one Hardware Change Guide with an ordered checklist, annotated before/after visuals, exact KiCad operations, reasons, warning dispositions, pin mappings, verification results, and a final manufacturing checklist. A fresh `CAD/Blip-PCB-Assembly.step` export is required after corrections, but a full enclosure is a parallel enhancement and does not block initial PCB approval; mounting features and mechanical clearances are still audited now. A human must open the edited project and complete the guide’s final visual review before approval or manufacturing. This hardware track is prioritized for Hack Club approval and may proceed in parallel with simulator-first Foundation Release software because the simulator does not depend on fabricated hardware.

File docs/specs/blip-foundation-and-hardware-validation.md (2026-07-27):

# Blip Hardware Validation and Foundation Release Specification

## Problem Statement

Blip has a promising routed PCB, early firmware, and a detailed product direction, but they do not yet form one buildable, reviewable system. The PCB has not been manufactured. Its current KiCad project identifies an inconsistent XIAO family, has unresolved ERC warnings, has not recorded schematic-to-PCB parity, and has not yet proven that display wiring, power, pin assignments, BOM entries, and firmware assumptions agree. Submitting it now would risk approval delays or manufactured hardware that needs rework.

At the same time, waiting for fabricated hardware would unnecessarily block the macOS product. The existing firmware performs too much host-dependent behavior directly and does not provide the stable device-event boundary needed by the Blip Agent, Control Center, or automated tests. Blip therefore needs an urgent, minimal-change Hardware Validation Gate and a parallel simulator-first Foundation Release that converge on the same protocol and pin map.

The result must also be understandable and honestly reproducible by Moksh for Macondo and Stardance. Technical assistance cannot substitute for his authorship, review, journals, or final manufacturing decision.

## Solution

Deliver Blip through two coordinated workstreams.

The hardware workstream migrates only the authoritative KiCad sources into the repository, audits them against primary component documentation, and applies the smallest corrections needed for the exact XIAO ESP32-S3, the two displays, the MCP23017, the switch matrix, the encoders, USB-C-only power, socketed assembly, and firmware-facing pin map. It produces a single visual Hardware Change Guide containing ordered edits, before-and-after evidence, warning dispositions, automated validation results, mechanical checks, and a final human review checklist. Manufacturing remains blocked until this gate passes.

The software workstream builds a high-fidelity virtual Blip Device first. Simulated and physical input enter the same versioned device-event boundary in the Blip Agent. That Agent owns configuration, persistence, host actions, Pomodoro state, display composition, audit history, and private communication with Control Center. Firmware retains scanning, Offline Controls, display rendering, device state, and protocol transport. This makes the complete Foundation Release testable before the PCB exists, then allows physical hardware to replace the simulator without changing product behavior.

Both workstreams use two release-level acceptance seams:

1. Authoritative KiCad project to automated electrical and consistency evidence to the Hardware Change Guide and final human visual review.
2. Simulated or physical device event through the shared Blip Agent pipeline to a dry-run action result, semantic display state, and Control Center observation.

## User Stories

1. As Moksh, I want the Hardware Validation Gate prioritized, so that I can seek Hack Club approval without waiting for the complete macOS application.
2. As Moksh, I want software development to proceed with a virtual Blip Device, so that fabrication lead time does not block progress.
3. As Moksh, I want one authoritative KiCad project in the repository, so that reviewers and tools inspect the same design.
4. As Moksh, I want automatic backups, lock files, local preferences, and unrelated starter projects excluded, so that submission evidence is unambiguous.
5. As Moksh, I want existing placement, routing, and matrix topology preserved unless a concrete defect is found, so that validation does not become a PCB redesign.
6. As Moksh, I want every required hardware correction collected in one Hardware Change Guide, so that I do not have to reconstruct decisions from chat history.
7. As Moksh, I want annotated before-and-after visuals for hardware corrections, so that I can understand and verify each change in KiCad.
8. As Moksh, I want exact ordered KiCad operations in the guide, so that I can reproduce or inspect each correction myself.
9. As a Hack Club reviewer, I want the controller identified consistently as the XIAO ESP32-S3, so that the design does not mix incompatible XIAO variants.
10. As a firmware developer, I want a single verified pin map shared by schematic, PCB, firmware, and documentation, so that electrical connections match software behavior.
11. As Moksh, I want every ERC warning fixed or explicitly justified, so that ignored problems do not masquerade as a passing design.
12. As Moksh, I want DRC run with zero unexplained violations and zero unconnected items, so that layout defects are found before manufacturing.
13. As Moksh, I want schematic-to-PCB parity run and recorded, so that a clean DRC cannot hide stale layout data.
14. As Moksh, I want ignored ERC and DRC tests reviewed individually, so that the gate records whether each exclusion is safe.
15. As a hardware builder, I want the Newhaven display configured for 3.3-volt I2C operation with defined control pins, so that it powers up predictably.
16. As a firmware developer, I want the graphical OLED at `0x3C` and the Newhaven display at `0x3D`, so that both can share the bus without an address collision.
17. As a hardware builder, I want combined I2C pull-up strength verified, so that multiple module pull-ups do not create an unreliable bus.
18. As a hardware builder, I want a worst-case 3.3-volt current budget, so that the XIAO regulator can safely power both displays and the expander.
19. As a hardware builder, I want local decoupling and bulk capacitance reviewed, so that display and input activity do not destabilize the device.
20. As a hardware builder, I want USB-C to be the only power source, so that revision one avoids unsafe or ambiguous power paths.
21. As a hardware builder, I want a warning against externally driving 3.3 volts while USB is connected, so that assembly and debugging remain safe.
22. As a hardware builder, I want the XIAO, MCP23017, and both displays removable, so that expensive or programmable parts can be repaired or replaced.
23. As a hardware builder, I want socket and header orientations, installed heights, and USB-C access checked, so that the assembled parts physically fit and remain usable.
24. As Moksh, I want left and right encoders clearly identified in schematic, silkscreen, firmware, and documentation, so that control mappings do not depend on ambiguous A/B/C/D net names.
25. As a user, I want encoder direction invertible in configuration, so that clockwise behavior can be corrected without PCB rework.
26. As a firmware developer, I want the existing matrix diode direction and row/column arrangement retained when continuity and scan logic agree, so that cosmetic changes do not introduce risk.
27. As Moksh, I want a fresh PCB assembly STEP export after corrections, so that mechanical evidence reflects the actual validated board.
28. As Moksh, I want mounting holes, display placement, encoder clearance, sockets, and USB access reviewed now, so that deferring the enclosure does not hide board-level mechanical defects.
29. As Moksh, I want a final manufacturing checklist and an explicit human sign-off, so that automation never silently authorizes fabrication.
30. As Moksh, I want the evidence package suitable for both Macondo and Stardance, so that the same truthful technical record can support both programs.
31. As Moksh, I want to write journals in my own words with authentic screenshots, photos, and time records, so that the submissions preserve my authorship.
32. As a reviewer, I want no fabricated evidence or double-counted work hours, so that the project record is trustworthy.
33. As a user, I want one macOS installation containing Control Center and the Blip Agent, so that Blip behaves like one product.
34. As a user, I want the Blip Agent to continue operating when Control Center is closed, so that physical controls and timers remain reliable.
35. As a user, I want an explicit, reversible login-item setup, so that background operation happens only with my consent.
36. As a user, I want to choose a physical or virtual Blip Device during setup, so that I can use the product before hardware arrives.
37. As a developer, I want virtual and physical device events to enter the same Agent boundary, so that simulator success predicts hardware behavior.
38. As a developer, I want the simulator to emit switch down/up, encoder rotation, and encoder press events, so that complete interactions can be tested.
39. As a developer, I want the simulator to model latency, stale heartbeats, malformed messages, incompatible versions, disconnections, and action failures, so that failure behavior is testable.
40. As a developer, I want a simulator CLI, so that end-to-end acceptance tests can run without manually operating the UI.
41. As a user, I want simulated state clearly labeled, so that I never mistake it for a connected physical device.
42. As a device developer, I want versioned newline-delimited JSON with handshakes, sequence numbers, timestamps, heartbeats, and acknowledgements, so that firmware and Agent communication is observable and recoverable.
43. As a user, I want malformed or unknown device messages handled safely, so that one bad packet cannot execute an unintended action.
44. As a user, I want Offline Controls executed exactly once by firmware, so that the Agent does not duplicate volume or media commands.
45. As a user, I want right-encoder rotation to control volume and its normal press to toggle play/pause, so that essential media controls work without the Agent.
46. As a user, I want an active Pomodoro alarm to temporarily make right-encoder press dismiss the alarm, so that dismissal is immediate and physical.
47. As a user, I want SW11 to cycle Main, Coding, and Research even while offline, so that the current Profile remains available.
48. As a user, I want SW12 and profile-dependent actions to report clearly when the Agent is offline, so that failed host actions are not silent.
49. As a user, I want the left encoder to browse contextual choices without activating them until pressed, so that rotation cannot accidentally launch an action.
50. As a user, I want the Context Browser configurable or disableable per Profile, so that each workflow can use the left encoder appropriately.
51. As a user, I want exactly three stable Profiles with editable presentation and mappings, so that configuration remains flexible without making physical Profile switching unpredictable.
52. As a user, I want SW11 and SW12 mappings locked, so that imports cannot remove recovery and navigation controls.
53. As a user, I want the Blip Agent to own the authoritative Blip Configuration in SQLite, so that all interfaces see consistent state.
54. As a user, I want validated JSON import and export without credentials, so that I can back up configuration safely.
55. As a user, I want unknown imported action types preserved but disabled, so that forward-compatible data is not silently discarded or executed.
56. As a user, I want integration secrets and sessions stored in Keychain, so that backups and logs do not leak them.
57. As a user, I want Control Center to communicate with the Agent through a current-user-only Unix-domain socket, so that no network port is exposed.
58. As a user, I want clear Agent restart and diagnostic recovery, so that a broken background connection is understandable.
59. As a user, I want code-defined, versioned action types with schemas, validation, permissions, dry runs, and documentation, so that configurable actions remain safe.
60. As a user, I want imported or newly configured risky actions previewed and approved before physical execution, so that configuration cannot surprise me.
61. As a user, I want destructive or externally visible actions to require confirmation, so that a hardware press cannot accidentally publish or destroy work.
62. As a user, I want every action execution recorded in a redacted structured audit, so that I can understand what Blip did.
63. As a user, I want dry-run and Test modes to show intended effects without performing them, so that mappings can be verified safely.
64. As a user, I want the small graphical display to show Persistent Status, so that Pomodoro, media, and connection state remain glanceable.
65. As a user, I want the large character display to show Contextual Status, so that active Profiles, choices, progress, results, and errors are readable.
66. As a user, I want safety errors, alarms, progress, Context Browser, normal status, and Ambient Status to follow one priority system, so that important information is not overwritten.
67. As a user, I want useful Ambient Status such as time, date, weather, current project, and connection health only when space is available, so that idle displays remain useful without becoming distracting.
68. As a user, I want Open-Meteo weather for a manually selected city with caching, units, attribution, and stale markers, so that weather works without location permission or an API key.
69. As a user, I want semantic display scenes rendered locally by firmware, so that animation remains smooth without streaming frames over serial.
70. As a user, I want unknown animation identifiers to fall back to static content, so that protocol-version differences remain usable.
71. As a user, I want reduced-motion and animation timing controls, so that display motion matches my preference.
72. As a user, I want Pomodoro state to survive Control Center closure, Agent restart, device disconnection, and Mac sleep, so that the timer remains trustworthy.
73. As a user, I want pause, reset, Add 5 Minutes, and explicit work/break transitions, so that I control session timing.
74. As a user, I want a macOS notification and configurable one-shot alarm at each phase transition, so that I notice completion away from the device.
75. As a user, I want Test Alarm and notification-permission guidance, so that I can verify alerts before relying on them.
76. As a user, I want physical displays to show timer completion even when Focus suppresses a Mac notification, so that DND cannot hide the event entirely.
77. As a user, I want a guided Apple Shortcut integration for Focus/DND, so that Blip uses supported macOS automation rather than private APIs.
78. As a user, I want Focus Mode to compose Pomodoro, media, workspace opening, and optional DND automation with partial-failure reporting, so that one failed step does not cancel everything.
79. As a user, I want one Active Media Source at a time, so that Spotify, Telegram, and system playback do not compete.
80. As a non-Premium Spotify user, I want Blip to open saved Spotify links and rely on system media controls, so that the initial integration works without unavailable Web API playback.
81. As an Arc user, I want explicit current-tab Research capture with clipboard restoration and permission-aware screenshot support, so that Blip does not depend on Chrome.
82. As a user, I want operational logs rotated and sensitive data redacted, so that diagnostics do not become indefinite surveillance.
83. As a user, I want storage reported and clearable by category, so that cache removal does not accidentally delete configuration or audits.
84. As a user, I want a hardware-centered Control Center with live display previews and direct key-map Test/Edit modes, so that configuration matches the physical object.
85. As a user, I want a polished macOS visual language with purposeful motion and coherent profile colors, so that Control Center feels intentionally designed rather than generically generated.
86. As a user, I want system light/dark appearance and accessible reduced motion, so that Control Center respects macOS preferences.
87. As a developer, I want a throwaway interactive UI prototype reviewed against real workflows before production implementation, so that visual decisions are tested cheaply.
88. As a developer, I want all executable code centralized under one source root while hardware and review artifacts stay in focused top-level areas, so that the repository is easy to navigate.
89. As a firmware developer, I want manual PlatformIO flashing in the Foundation Release, so that configuration work is not coupled to risky firmware update machinery.
90. As a user, I want firmware and protocol compatibility displayed clearly, so that an incompatible device produces setup guidance instead of undefined behavior.
91. As a user, I want permissions requested only when I enable dependent features, so that basic Blip operation does not demand unnecessary access.
92. As a developer, I want Foundation scope completed before Telegram, full Spotify Web API, Codex Feature Forge, and deep Research extraction, so that external integrations do not obscure the core loop.
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

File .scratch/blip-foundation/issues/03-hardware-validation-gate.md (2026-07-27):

# 03 — Pass and document the Hardware Validation Gate

**What to build:** Produce a reviewer-ready hardware evidence package that makes the final human manufacturing decision clear and reproducible.

**Blocked by:** 02 — Apply minimal controller, power, and display corrections.

**Status:** automated evidence complete; human sign-off required

- [x] ERC, DRC, schematic parity, unconnected-item, BOM, and pin-map checks pass or have explicit justified dispositions.
- [ ] A fresh partial STEP export exists; complete socket/display/encoder height validation remains part of Moksh's physical sign-off.
- [x] The Hardware Change Guide contains ordered KiCad steps and annotated before/after evidence.
- [x] Moksh has a final visual review and manufacturing checklist that automation cannot sign for him.

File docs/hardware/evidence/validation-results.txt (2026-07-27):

Hardware Validation Gate — 2026-07-21
KiCad GUI DRC: 0 violations
KiCad GUI unconnected items: 0
KiCad GUI schematic parity: 0 (operator-attested; see drc-parity.png)
KiCad CLI ERC: 0 errors, 0 warnings
Source revision baseline for before image: e0d795d

SHA-256 source/artifact binding:
f79d08c769c496a55742e05853f6230a7aeb586b1f47ecbe2a25918c5321c711  PCB/Hackpad.kicad_pcb
0e567b836aea6845e7e5a3d91c0b53fd1ea921ee4473b3919087f548ef2fc913  PCB/Hackpad.kicad_sch
cbebbfc431b908c46b2509805ab4363082077aea9656cf4717e7243385285020  PCB/Blip.pretty/XIAO_ESP32S3_Socket.kicad_mod
d8c1aa42e53af8127d99fc2cb34fe868f9aad859bb383313cd3f733fd328e3e2  PCB/Hackpad.kicad_pro
7b270faf3ec9d4e021f46e35a76ad9c187889cf0fbb7587f1ed069805860d662  docs/hardware/evidence/erc.rpt
fa44ee15d3d5dc96c8e182c97d8db4636f09b909d99e3f42596480024264b644  docs/hardware/evidence/drc.rpt
db56be55e5ca103b130b174c5da5bb912b6725b731ce665d24db473a1cfad1a7  CAD/Blip-PCB-Assembly.step
eaac2ac2d055971c2f96e0fb33dd5323bb6a367071d8f35fd2c99b1d09541593  docs/hardware/evidence/board-before-e0d795d.svg
ff2ff135aca204d3e87a5e7aebb78241627b427e5889ee19a3bfebfb601265ab  docs/hardware/evidence/board-after.svg
21f75690a5a846b8f900e2aba97654dba9be4a542974d0e4ac656791a6958696  docs/hardware/evidence/drc-parity.png
2d0f5199790c76a218b8ae0d182e174bc43df0ef02278d77c1046696d1484534  docs/hardware/evidence/before-after-annotated.svg

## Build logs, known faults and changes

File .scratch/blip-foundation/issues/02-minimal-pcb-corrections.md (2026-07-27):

# 02 — Apply minimal controller, power, and display corrections

**What to build:** Make only the evidence-backed schematic and PCB changes required for the exact XIAO ESP32-S3, USB-C-only power, both OLEDs, the MCP23017, and repairable assembly.

**Blocked by:** 01 — Establish the authoritative Blip hardware baseline.

**Status:** electrical corrections applied; manufacturing verification remains open in ticket 03

- [x] The XIAO ESP32-S3 symbol, official header-center geometry, pins, BOM identity, and firmware contract agree.
- [x] Newhaven 3.3 V I2C control levels and `0x3D` address are defined; the graphical OLED remains `0x3C`.
- [ ] Pull-ups and connector parts are defined, but worst-case current/thermal behavior, connector orientation and height, USB access, and decoupling performance still require the Hardware Validation Gate.
- [x] Existing routing and matrix topology remain unless a documented defect requires change.

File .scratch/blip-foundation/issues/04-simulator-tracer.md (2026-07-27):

# 04 — Prove the simulator-to-Agent tracer bullet

**What to build:** Make one virtual switch action travel through the real device-event boundary, Blip Agent, safe dry run, semantic displays, and a minimal Control Center diagnostic view.

**Blocked by:** None — can start immediately.

**Status:** ready-for-agent

- [ ] Executable source is centralized under the agreed source root.
- [ ] The virtual Blip Device emits switch and encoder events through the same boundary intended for physical serial.
- [ ] One event produces a dry-run action result, audit entry, and both semantic display states.
- [ ] A CLI scenario and minimal Control Center view demonstrate the complete path.

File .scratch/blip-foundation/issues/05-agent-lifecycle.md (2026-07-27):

# 05 — Prove the bundled Agent lifecycle and private IPC

**What to build:** Make Control Center communicate with a long-running Blip Agent through private local IPC while presenting clear, reversible lifecycle controls.

**Blocked by:** 04 — Prove the simulator-to-Agent tracer bullet.

**Status:** ready-for-agent

- [ ] Current-user-only versioned Unix-domain IPC carries the tracer scenario.
- [ ] The Agent continues operating after Control Center closes and reconnects when it returns.
- [ ] Login-item consent, session-only operation, restart, disconnect, and incompatible-version states are visible.
- [ ] The unsigned Apple Silicon development build runs on the target Mac.

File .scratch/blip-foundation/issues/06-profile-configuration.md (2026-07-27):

# 06 — Configure and persist the three stable Profiles

**What to build:** Let Main, Coding, and Research mappings be safely edited, persisted, backed up, and exercised through simulated input.

**Blocked by:** 04 — Prove the simulator-to-Agent tracer bullet; 05 — Prove the bundled Agent lifecycle and private IPC.

**Status:** ready-for-agent

- [ ] SQLite authoritatively stores exactly `main`, `coding`, and `research` with immutable order.
- [ ] SW11 and SW12 mappings cannot be changed by editing or import.
- [ ] Validated JSON import/export omits credentials and preserves unknown action types disabled.
- [ ] Simulated Profile switching updates Agent, Control Center, and display state.

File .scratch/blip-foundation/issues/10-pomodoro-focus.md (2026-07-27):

# 10 — Persist Pomodoro and deliver DND-aware alarms

**What to build:** Make the Agent-owned Pomodoro trustworthy across runtime interruptions and noticeable through Mac and device feedback.

**Blocked by:** 05 — Prove the bundled Agent lifecycle and private IPC; 08 — Ship the production Control Center foundation; 09 — Compose prioritized status for both displays.

**Status:** ready-for-agent

- [ ] Work/break, pause, reset, Add 5 Minutes, sleep, restart, and reconnect behavior use a controllable persisted clock model.
- [ ] Notifications, one-shot alarms, Test Alarm, actions, and right-encoder dismissal are represented in simulation.
- [ ] Apple Shortcut Focus/DND setup uses supported APIs and reports partial failure.
- [ ] Displays always show completion when macOS Focus suppresses a notification.

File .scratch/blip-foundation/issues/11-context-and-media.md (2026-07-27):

# 11 — Deliver Context Browser and essential media behavior

**What to build:** Make the left encoder browse and activate Profile choices while the right encoder and one Active Media Source behave predictably.

**Blocked by:** 07 — Execute safe versioned actions end to end; 09 — Compose prioritized status for both displays.

**Status:** ready-for-agent

- [ ] Left rotation previews, press activates, timeout restores status, and direction can be inverted.
- [ ] Context Browser choices are configurable per Profile and Agent unavailability is explicit.
- [ ] System media and saved Spotify links work without requiring Premium or inventing metadata.
- [ ] Only one Blip-managed media source is active and restart never resumes playback automatically.

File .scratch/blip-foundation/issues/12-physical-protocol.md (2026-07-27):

# 12 — Connect physical firmware and Offline Controls

**What to build:** Connect the XIAO ESP32-S3 through the shared protocol and prove that physical input ownership matches simulator behavior without duplicate actions.

**Blocked by:** 01 — Establish the authoritative Blip hardware baseline; 02 — Apply minimal controller, power, and display corrections; 04 — Prove the simulator-to-Agent tracer bullet; 06 — Configure and persist the three stable Profiles.

**Status:** ready-for-agent

- [ ] Versioned JSONL handshake, sequencing, timestamps, heartbeats, acknowledgements, limits, reconnect, and malformed handling are verified.
- [ ] Right encoder performs volume and play/pause offline and is never re-executed by the Agent.
- [ ] SW11 cycles device-owned Profiles offline and reconciles without duplicate actions.
- [ ] SW12 and Agent-owned inputs clearly report offline behavior; manual PlatformIO flashing is documented.

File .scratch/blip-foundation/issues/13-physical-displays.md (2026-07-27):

# 13 — Render semantic scenes on the physical displays

**What to build:** Make both physical OLEDs render the same semantic scenes and timing behavior already proven by the simulator.

**Blocked by:** 02 — Apply minimal controller, power, and display corrections; 09 — Compose prioritized status for both displays; 12 — Connect physical firmware and Offline Controls.

**Status:** ready-for-agent

- [ ] The graphical OLED renders Persistent Status at `0x3C` and the Newhaven renders Contextual Status at `0x3D`.
- [ ] Firmware renders built-in animations locally and direct diagnostic text remains available.
- [ ] Unknown scenes fall back safely and update-size/rate limits protect the device.
- [ ] Reconnect, offline scenes, reduced motion, and simulator parity are verified on hardware.

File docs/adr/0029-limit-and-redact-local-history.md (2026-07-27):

# Limit and redact local history

Operational logs rotate after 30 days or 100 MB by default, whichever comes first, and redact credentials, authorization data, phone numbers, clipboard and captured-page contents, and sensitive query parameters. Explicit Codex and Feature Forge runs may retain their prompts and command output, with Feature Forge audits preserved until the user archives or deletes them. Telegram cache, Research captures, operational logs, and audit records have separate storage controls; cache clearing never removes configuration or audits, destructive clearing explains its scope, diagnostic exports are redacted and previewed, and Control Center reports storage by category.

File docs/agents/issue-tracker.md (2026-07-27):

# Issue tracker: GitHub

Issues and PRDs for this repo live as GitHub issues. Use the `gh` CLI for all operations.

## Conventions

- **Create an issue**: `gh issue create --title "..." --body "..."`. Use a heredoc for multi-line bodies.
- **Read an issue**: `gh issue view <number> --comments`, filtering comments by `jq` and also fetching labels.
- **List issues**: `gh issue list --state open --json number,title,body,labels,comments --jq '[.[] | {number, title, body, labels: [.labels[].name], comments: [.comments[].body]}]'` with appropriate `--label` and `--state` filters.
- **Comment on an issue**: `gh issue comment <number> --body "..."`
- **Apply / remove labels**: `gh issue edit <number> --add-label "..."` / `--remove-label "..."`
- **Close**: `gh issue close <number> --comment "..."`

Infer the repo from `git remote -v` — `gh` does this automatically when run inside a clone.

## Pull requests as a triage surface

**PRs as a request surface: no.** _(Set to `yes` if this repo treats external PRs as feature requests; `/triage` reads this flag.)_

When set to `yes`, PRs run through the same labels and states as issues, using the `gh pr` equivalents:

- **Read a PR**: `gh pr view <number> --comments` and `gh pr diff <number>` for the diff.
- **List external PRs for triage**: `gh pr list --state open --json number,title,body,labels,author,authorAssociation,comments` then keep only `authorAssociation` of `CONTRIBUTOR`, `FIRST_TIME_CONTRIBUTOR`, or `NONE`.
- **Comment / label / close**: `gh pr comment`, `gh pr edit --add-label`/`--remove-label`, `gh pr close`.

GitHub shares one number space across issues and PRs, so resolve a bare number with `gh pr view` and fall back to `gh issue view`.

## When a skill says "publish to the issue tracker"

Create a GitHub issue.

## When a skill says "fetch the relevant ticket"

Run `gh issue view <number> --comments`.

## Wayfinding operations

Used by `/wayfinder`. The map is a single issue with child issues as tickets.

- **Map**: An issue labelled `wayfinder:map`, holding Notes, Decisions-so-far, and Fog.
- **Child ticket**: A GitHub sub-issue linked to the map and labelled `wayfinder:<type>`.
- **Blocking**: Use GitHub’s native issue dependencies. Fall back to a `Blocked by:` line if unavailable.
- **Frontier query**: Choose the first unassigned open child without open blockers.
- **Claim**: `gh issue edit <n> --add-assignee @me`.
- **Resolve**: Comment with the answer, close the ticket, and append its context pointer to the map.

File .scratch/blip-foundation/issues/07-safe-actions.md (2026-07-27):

# 07 — Execute safe versioned actions end to end

**What to build:** Provide code-defined basic macOS actions that can be configured, tested, dry-run, approved, executed, audited, and displayed safely.

**Blocked by:** 06 — Configure and persist the three stable Profiles.

**Status:** ready-for-agent

- [ ] Each action type has a stable identity, schema, validation, permissions, dry-run behavior, and display feedback.
- [ ] Imports never execute actions and risky new mappings require approval.
- [ ] Destructive or externally visible actions require confirmation and unsafe force operations are unavailable.
- [ ] Redacted audits capture result, timing, Profile, and physical or simulated origin.

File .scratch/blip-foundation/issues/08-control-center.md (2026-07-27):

# 08 — Ship the production Control Center foundation

**What to build:** Validate a throwaway interaction prototype, then ship the approved hardware-centered macOS interface for daily Foundation workflows.

**Blocked by:** 05 — Prove the bundled Agent lifecycle and private IPC; 06 — Configure and persist the three stable Profiles; 07 — Execute safe versioned actions end to end.

**Status:** ready-for-agent

- [ ] A throwaway prototype validates dashboard, display preview, mapping, Test/Edit, and simulator workflows before production code.
- [ ] Production UI follows the locked graphite/warm-off-white and amber/blue/teal visual language without generic AI aesthetics.
- [ ] Connection, permissions, Profiles, mappings, tests, logs, storage, and diagnostics are usable.
- [ ] Light/dark appearance, keyboard access, VoiceOver labels, contrast, and reduced motion are verified.

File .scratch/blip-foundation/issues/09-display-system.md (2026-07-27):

# 09 — Compose prioritized status for both displays

**What to build:** Make one semantic display system drive accurate Persistent, Contextual, temporary, error, menu, and Ambient Status in simulation.

**Blocked by:** 04 — Prove the simulator-to-Agent tracer bullet; 06 — Configure and persist the three stable Profiles.

**Status:** ready-for-agent

- [ ] Safety, alarms, progress, Context Browser, normal, and ambient scenes follow the locked priority order.
- [ ] Small and large display previews enforce their distinct roles and reserved regions.
- [ ] Expiry, acknowledgement, coalescing, rate limits, unknown-animation fallback, and reduced motion are tested.
- [ ] Manual-location Open-Meteo weather is cached, attributed, and marked stale without blocking core operation.

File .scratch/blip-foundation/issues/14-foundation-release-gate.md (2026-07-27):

# 14 — Pass the complete Foundation Release gate

**What to build:** Demonstrate one coherent Blip installation and evidence package that passes both release-level acceptance seams on the target Mac and validated hardware.

**Blocked by:** 03 — Pass and document the Hardware Validation Gate; 08 — Ship the production Control Center foundation; 10 — Persist Pomodoro and deliver DND-aware alarms; 11 — Deliver Context Browser and essential media behavior; 12 — Connect physical firmware and Offline Controls; 13 — Render semantic scenes on the physical displays.

**Status:** ready-for-agent

- [ ] Headless simulator scenarios prove lifecycle, Profiles, safe actions, displays, Pomodoro, faults, permissions, privacy, and diagnostics.
- [ ] Physical-device scenarios reuse the same acceptance definitions and replace only transport/render adapters.
- [ ] Installation, login-item consent, manual firmware guidance, Control Center closure, recovery, and storage controls pass on the target Mac.
- [ ] The Foundation Release is usable without Telegram, full Spotify Web API, Arc extraction, Codex, or Feature Forge.

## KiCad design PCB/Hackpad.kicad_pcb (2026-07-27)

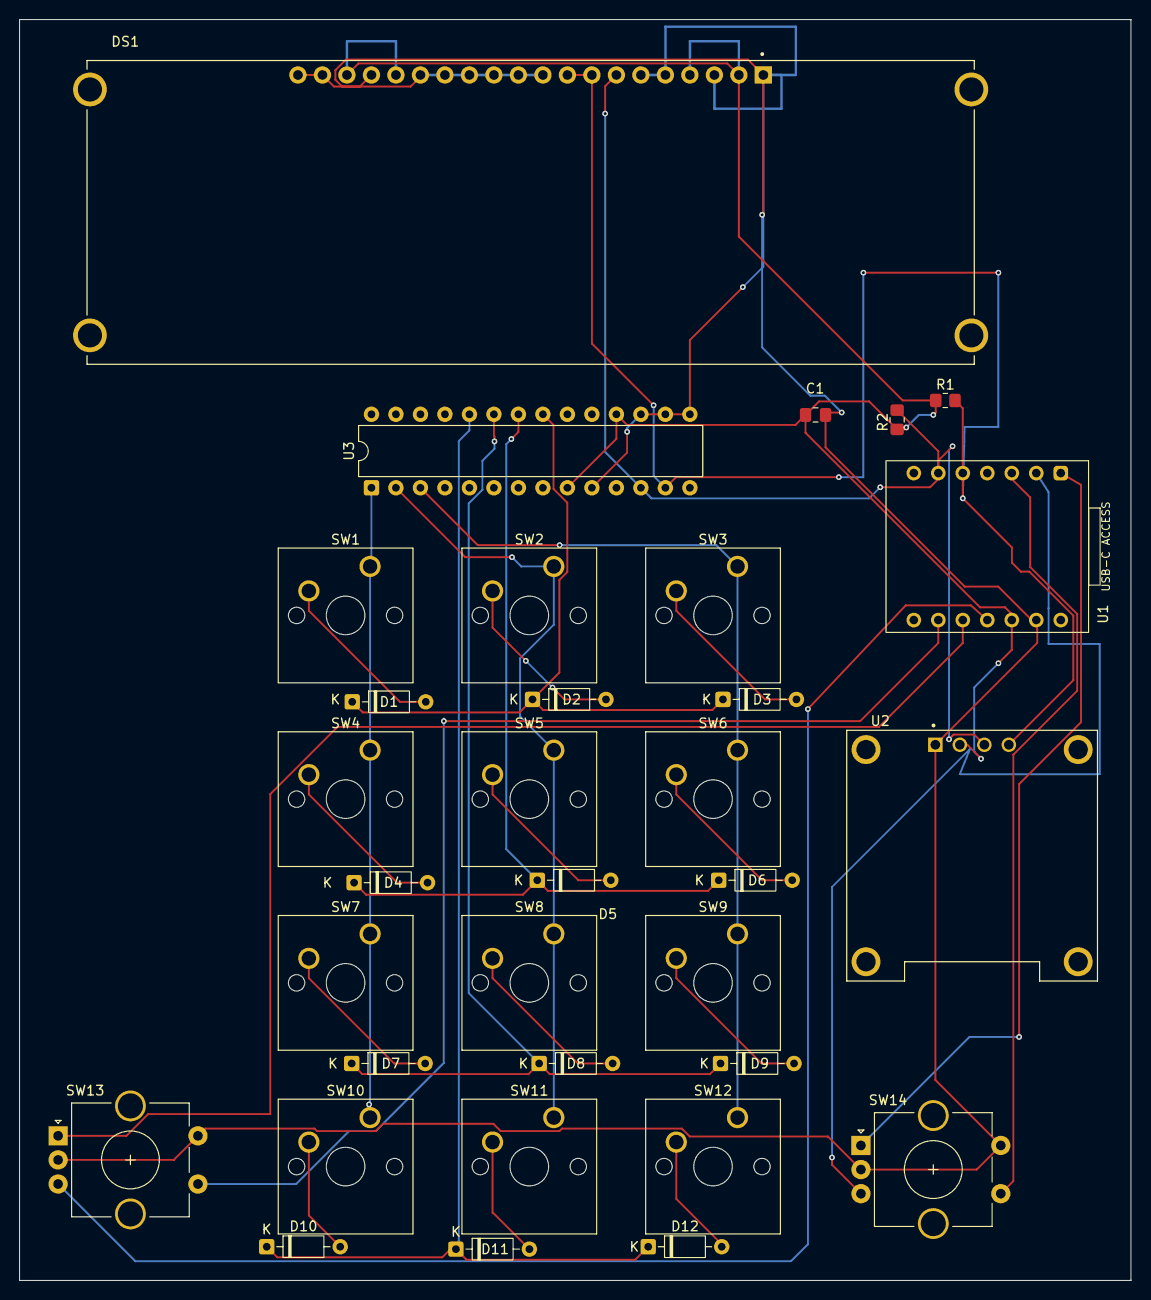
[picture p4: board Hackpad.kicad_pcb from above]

Board: 2 copper layers, 115.2 x 130.8 mm, 33 parts (0 on the bottom side), 29 nets.

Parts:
C1: 100nF; C_0805_2012Metric_Pad1.18x1.45mm_HandSolder
D1, D2, D3, D4, D5, D6, D7, D8, D9, D10, D11, D12: 1N4148; D_DO-35_SOD27_P7.62mm_Horizontal
DS1: NHD-0420CW-AB3; LCD_NHD-0420CW-AB3
R1, R2: 4.7k; R_0805_2012Metric_Pad1.20x1.40mm_HandSolder
SW1, SW2, SW3, SW4, SW5, SW6, SW7, SW8, SW9, SW10, SW11, SW12: SW_Cherry_MX_1.00u_PCB
SW13, SW14: RotaryEncoder_Switch; RotaryEncoder_Alps_EC11E-Switch_Vertical_H20mm_CircularMoun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
U1: Seeed Studio XIAO ESP32-S3; XIAO_ESP32S3_Socket
U2: DM-OLED096-636; MODULE_DM-OLED096-636
U3: MCP23017x-x-SP; DIP-28_W7.62mm

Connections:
+3.3V: C1.1, DS1.2 (VDD), DS1.4 (D/C/NC/SA0), DS1.16 (~RES), DS1.18 (BS1), R1.1, R2.1, U1.12 (3V3_12), U2.2 (VCC_IN), U3.9 (V_{DD}), U3.18 (~RESET)
/COL0: SW1.1, SW4.1, SW7.1, SW10.1, U3.1 (GPB0)
/COL1: SW2.1, SW5.1, SW8.1, SW11.1, U3.2 (GPB1)
/COL2: SW3.1, SW6.1, SW9.1, SW12.1, U3.3 (GPB2)
/ENC_A: SW13.A, U1.10 (GPIO8_A9_D9_MISO)
/ENC_B: SW13.B, U1.11 (GPIO9_A10_D10_MOSI)
/ENC_C: SW14.A, U1.1 (GPIO1_A0_D0)
/ENC_D: SW14.B, U1.2 (GPIO2_A1_D1)
/ENC_SW: SW13.S1, U1.9 (GPIO7_A8_D8_SCK)
/ENC_SW1: SW14.S1, U1.3 (GPIO3_A2_D2)
/ROW0: D1.1 (K), D2.1 (K), D3.1 (K), U3.21 (GPA0)
/ROW1: D4.1 (K), D5.1 (K), D6.1 (K), U3.22 (GPA1)
/ROW2: D7.1 (K), D8.1 (K), D9.1 (K), U3.23 (GPA2)
/ROW3: D10.1 (K), D11.1 (K), D12.1 (K), U3.24 (GPA3)
/SCL: DS1.7 (DB0/SCLK/SCL), R2.2, U1.6 (GPIO6_A5_D5_SCL), U2.3 (SCL), U3.12 (SCK)
/SDA: DS1.8 (DB1/SDI/SDAIN), DS1.9 (DB2/SDO/SDAOUT), R1.2, U1.5 (GPIO5_A4_D4_SDA), U2.4 (SDA), U3.13 (SDA)
GND: C1.2, DS1.1 (VSS), DS1.3 (REGVDD), DS1.5 (R/W/NC), DS1.6 (E/NC), DS1.10 (DB3/NC), DS1.11 (DB4/NC), DS1.12 (DB5/NC), DS1.13 (DB6/NC), DS1.14 (DB7/NC), DS1.15 (~CS/NC), DS1.17 (BS0), DS1.19 (BS2), DS1.20 (VSS), SW13.C, SW13.S2, SW14.C, SW14.S2, U1.13 (GND_13), U2.1 (GND), U3.10 (V_{SS}), U3.15 (A0), U3.16 (A1), U3.17 (A2)
unnamed: D1.2 (A), SW1.2
unnamed: D2.2 (A), SW2.2
unnamed: D3.2 (A), SW3.2
unnamed: D4.2 (A), SW4.2
unnamed: D5.2 (A), SW5.2
unnamed: D6.2 (A), SW6.2
unnamed: D7.2 (A), SW7.2
unnamed: D8.2 (A), SW8.2
unnamed: D9.2 (A), SW9.2
unnamed: D10.2 (A), SW10.2
unnamed: D11.2 (A), SW11.2
unnamed: D12.2 (A), SW12.2

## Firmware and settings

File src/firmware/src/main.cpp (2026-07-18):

#include <Adafruit_MCP23X17.h>
#include <Adafruit_SSD1306.h>
#include <USB.h>
#include <USBHIDConsumerControl.h>
#include <USBHIDKeyboard.h>
#include <Wire.h>

#include "CharacterOled.h"
#include "Config.h"

// PCB net mapping from Hackpad.kicad_sch.
constexpr uint8_t SDA_PIN = D4;
constexpr uint8_t SCL_PIN = D5;
constexpr uint8_t ENCODER1_A = D9;
constexpr uint8_t ENCODER1_B = D10;
constexpr uint8_t ENCODER1_SW = D8;
constexpr uint8_t ENCODER2_A = D0;
constexpr uint8_t ENCODER2_B = D1;
constexpr uint8_t ENCODER2_SW = D2;
constexpr uint8_t MCP_ADDRESS = 0x20;
constexpr uint8_t GRAPHIC_ADDRESS = 0x3C;
constexpr uint8_t CHARACTER_ADDRESS = 0x3D;
constexpr uint16_t DEBOUNCE_MS = 20;
constexpr uint16_t DISPLAY_REFRESH_MS = 150;
constexpr uint16_t LONG_PRESS_MS = 3000;

Adafruit_MCP23X17 mcp;
Adafruit_SSD1306 graphic(128, 64, &Wire, -1);
CharacterOled character;
ConfigStore config;
USBHIDKeyboard keyboard;
USBHIDConsumerControl consumer;

bool mcpReady = false;
bool graphicReady = false;
bool characterReady = false;
bool configDirty = false;
String lastAction = "Ready";
uint32_t lastDisplayRefresh = 0;

struct KeyState {
  bool raw = false;
  bool stable = false;
  uint32_t changedAt = 0;
};
KeyState keyStates[KEY_COUNT];

struct Encoder {
  Encoder(uint8_t a, uint8_t b, uint8_t button)
      : pinA(a), pinB(b), pinSwitch(button) {}

  uint8_t pinA;
  uint8_t pinB;
  uint8_t pinSwitch;
  uint8_t previousAB = 0;
  int8_t accumulator = 0;
  bool rawSwitch = false;
  bool stableSwitch = false;
  bool longPressHandled = false;
  uint32_t switchChangedAt = 0;
  uint32_t pressedAt = 0;
};
Encoder volumeEncoder{ENCODER1_A, ENCODER1_B, ENCODER1_SW};
Encoder profileEncoder{ENCODER2_A, ENCODER2_B, ENCODER2_SW};

const uint8_t KEY_CODES[] = {
    0, KEY_RETURN, KEY_ESC, KEY_TAB, ' ', KEY_BACKSPACE, KEY_DELETE,
    KEY_HOME, KEY_END, KEY_PAGE_UP, KEY_PAGE_DOWN, KEY_UP_ARROW,
    KEY_DOWN_ARROW, KEY_LEFT_ARROW, KEY_RIGHT_ARROW};
const char* KEY_NAMES[] = {
    "NONE", "ENTER", "ESC", "TAB", "SPACE", "BACKSPACE", "DELETE",
    "HOME", "END", "PAGE_UP", "PAGE_DOWN", "ARROW_UP", "ARROW_DOWN",
    "ARROW_LEFT", "ARROW_RIGHT"};

bool i2cPresent(uint8_t address) {
  Wire.beginTransmission(address);
  return Wire.endTransmission() == 0;
}

String scanI2c() {
  String found;
  for (uint8_t address = 1; address < 127; ++address) {
    if (!i2cPresent(address)) continue;
    if (!found.isEmpty()) found += ", ";
    char value[7];
    snprintf(value, sizeof(value), "0x%02X", address);
    found += value;
  }
  return found.isEmpty() ? "none" : found;
}

void reportDiagnostics() {
  bool graphicAck = i2cPresent(GRAPHIC_ADDRESS);
  bool characterAck = i2cPresent(CHARACTER_ADDRESS);
  Serial.println("\n=== Blip startup diagnostics ===");
  Serial.printf("I2C devices: %s\n", scanI2c().c_str());
  Serial.printf("MCP23017 0x20: %s\n", mcpReady ? "OK" : "MISSING");
  Serial.printf("128x64 OLED 0x3C: %s\n",
                graphicReady ? "OK" : (graphicAck ? "ACK, INIT FAILED" : "NO ACK"));
  Serial.printf("20x4 OLED 0x3D: %s\n",
                characterReady ? "OK" : (characterAck ? "ACK, INIT FAILED" : "NO ACK"));
  if (graphicAck && !characterAck) {
    Serial.println("WARNING: Newhaven display may still be at 0x3C; set its SA0 pin to 3.3V.");
  }
  Serial.println("USB HID: enabled (XIAO ESP32-S3)");
  Serial.println("Wi-Fi and Bluetooth: disabled");
  Serial.println("Commands: status | config | set-config <JSON> | reset-config | reboot");
  Serial.println("================================\n");
}

void tapMedia(uint16_t usage, const char* label) {
  if (usage) { consumer.press(usage); consumer.release(); }
  lastAction = label;
}

uint8_t functionKeyCode(uint8_t number) {
  if (number >= 1 && number <= 12) return KEY_F1 + number - 1;
  if (number >= 13 && number <= 24) return KEY_F13 + number - 13;
  return 0;
}

void executeAction(const char* action) {
  String name(action);
  name.toUpperCase();
  lastAction = name;
  if (name == "NONE") return;

  bool mediaAction = true;
  if (name == "MUTE") { consumer.press(CONSUMER_CONTROL_MUTE); consumer.release(); }
  else if (name == "VOLUME_UP") { consumer.press(CONSUMER_CONTROL_VOLUME_INCREMENT); consumer.release(); }
  else if (name == "VOLUME_DOWN") { consumer.press(CONSUMER_CONTROL_VOLUME_DECREMENT); consumer.release(); }
  else if (name == "MEDIA_PLAY_PAUSE") { consumer.press(CONSUMER_CONTROL_PLAY_PAUSE); consumer.release(); }
  else if (name == "MEDIA_NEXT") { consumer.press(CONSUMER_CONTROL_SCAN_NEXT); consumer.release(); }
  else if (name == "MEDIA_PREVIOUS") { consumer.press(CONSUMER_CONTROL_SCAN_PREVIOUS); consumer.release(); }
  else if (name == "MEDIA_STOP") { consumer.press(CONSUMER_CONTROL_STOP); consumer.release(); }
  else mediaAction = false;
  if (mediaAction) return;

  if (name.length() == 1) {
    keyboard.write(static_cast<uint8_t>(name[0]));
    return;
  }
  if (name.startsWith("CTRL_") && name.length() == 6) {
    keyboard.press(KEY_LEFT_CTRL);
    keyboard.press(static_cast<uint8_t>(tolower(name[5])));
    delay(5);
    keyboard.releaseAll();
    return;
  }
  if (name[0] == 'F') {
    uint8_t code = functionKeyCode(name.substring(1).toInt());
    if (code) keyboard.write(code);
    return;
  }
  for (size_t i = 0; i < sizeof(KEY_CODES) / sizeof(KEY_CODES[0]); ++i) {
    if (name == KEY_NAMES[i]) {
      keyboard.write(KEY_CODES[i]);
      return;
    }
  }
  lastAction = "Unknown: " + name;
}

void selectProfile(int8_t direction) {
  int next = config.activeProfile + direction;
  if (next < 0) next = PROFILE_COUNT - 1;
  if (next >= PROFILE_COUNT) next = 0;
  config.activeProfile = next;
  configDirty = true;
  lastAction = String("Profile: ") + config.profiles[next].name;
}

void setupEncoder(Encoder& encoder) {
  pinMode(encoder.pinA, INPUT_PULLUP);
  pinMode(encoder.pinB, INPUT_PULLUP);
  pinMode(encoder.pinSwitch, INPUT_PULLUP);
  encoder.previousAB = (digitalRead(encoder.pinA) << 1) | digitalRead(encoder.pinB);
}

int8_t readEncoderRotation(Encoder& encoder) {
  static const int8_t transitions[16] = {0, -1, 1, 0, 1, 0, 0, -1,
                                          -1, 0, 0, 1, 0, 1, -1, 0};
  uint8_t current = (digitalRead(encoder.pinA) << 1) | digitalRead(encoder.pinB);
  encoder.accumulator += transitions[(encoder.previousAB << 2) | current];
  encoder.previousAB = current;
  if (encoder.accumulator >= 4) {
    encoder.accumulator = 0;
    return 1;
  }
  if (encoder.accumulator <= -4) {
    encoder.accumulator = 0;
    return -1;
  }
  return 0;
}

enum class SwitchEvent { NONE, PRESSED, RELEASED, LONG_PRESS };
SwitchEvent readEncoderSwitch(Encoder& encoder) {
  bool raw = digitalRead(encoder.pinSwitch) == LOW;
  uint32_t now = millis();
  if (raw != encoder.rawSwitch) {
    encoder.rawSwitch = raw;
    encoder.switchChangedAt = now;
  }
  if (raw != encoder.stableSwitch && now - encoder.switchChangedAt >= DEBOUNCE_MS) {
    encoder.stableSwitch = raw;
    if (raw) {
      encoder.pressedAt = now;
      encoder.longPressHandled = false;
      return SwitchEvent::PRESSED;
    }
    return SwitchEvent::RELEASED;
  }
  if (encoder.stableSwitch && !encoder.longPressHandled &&
      now - encoder.pressedAt >= LONG_PRESS_MS) {
    encoder.longPressHandled = true;
    return SwitchEvent::LONG_PRESS;
  }
  return SwitchEvent::NONE;
}

void scanMatrix() {
  if (!mcpReady) return;
  uint32_t now = millis();
  for (uint8_t row = 0; row < 4; ++row) {
    for (uint8_t r = 0; r < 4; ++r) mcp.digitalWrite(r, HIGH);
    mcp.digitalWrite(row, LOW);
    delayMicroseconds(50);
    for (uint8_t column = 0; column < 3; ++column) {
      uint8_t index = row * 3 + column;
      bool pressed = mcp.digitalRead(8 + column) == LOW;
      KeyState& state = keyStates[index];
      if (pressed != state.raw) {
        state.raw = pressed;
        state.changedAt = now;
      }
      if (pressed != state.stable && now - state.changedAt >= DEBOUNCE_MS) {
        state.stable = pressed;
        if (pressed) executeAction(config.profiles[config.activeProfile].actions[index]);
      }
    }
  }
  for (uint8_t r = 0; r < 4; ++r) mcp.digitalWrite(r, HIGH);
}

void updateDisplays(bool force = false) {
  uint32_t now = millis();
  if (!force && now - lastDisplayRefresh < DISPLAY_REFRESH_MS) return;
  lastDisplayRefresh = now;
  bool connected = true;

  if (characterReady) {
    character.printPadded(0, "BLIP // " + String(config.profiles[config.activeProfile].name));
    character.printPadded(1, "USB: CONNECTED");
    character.printPadded(2, "LAST: " + lastAction.substring(0, 14));
    character.printPadded(3, "CFG: USB SERIAL");
  }
  if (graphicReady) {
    graphic.clearDisplay();
    graphic.drawRoundRect(0, 0, 128, 64, 7, SSD1306_WHITE);
    graphic.fillRect(0, 0, 128, 14, SSD1306_WHITE);
    graphic.setTextColor(SSD1306_BLACK);
    graphic.setTextSize(1);
    graphic.setCursor(6, 3);
    graphic.print("BLIP STATUS");
    graphic.setTextColor(SSD1306_WHITE);
    graphic.setCursor(7, 21);
    graphic.print("PROFILE ");
    graphic.print(config.activeProfile + 1);
    graphic.print("/3");
    graphic.setCursor(7, 34);
    graphic.print(config.profiles[config.activeProfile].name);
    graphic.setCursor(7, 49);
    graphic.print("USB LINKED");
    // Small connection glyph.
    graphic.drawCircle(115, 48, 7, SSD1306_WHITE);
    if (connected) graphic.fillCircle(115, 48, 3, SSD1306_WHITE);
    graphic.display();
  }
}

void handleSerial() {
  if (!Serial.available()) return;
  String command = Serial.readStringUntil('\n');
  command.trim();
  if (command == "status") reportDiagnostics();
  else if (command == "config") Serial.println(config.toJson());
  else if (command.startsWith("set-config ")) {
    String error;
    if (config.fromJson(command.substring(11), error) && config.save())
      Serial.println("Configuration saved.");
    else Serial.println("Configuration failed: " + error);
  }
  else if (command == "reset-config") {
    config.reset();
    Serial.println("Defaults restored.");
  } else if (command == "reboot") ESP.restart();
  else Serial.println("Unknown command. Try: status | config | set-config <JSON> | reset-config | reboot");
}

void setup() {
  Serial.begin(115200);
  Serial.setTimeout(20);
  delay(400);
  config.begin();
  Wire.begin(SDA_PIN, SCL_PIN);
  Wire.setClock(400000);

  mcpReady = mcp.begin_I2C(MCP_ADDRESS, &Wire);
  if (mcpReady) {
    for (uint8_t row = 0; row < 4; ++row) {
      mcp.pinMode(row, OUTPUT);
      mcp.digitalWrite(row, HIGH);
    }
    for (uint8_t column = 0; column < 3; ++column) mcp.pinMode(8 + column, INPUT_PULLUP);
  }
  graphicReady = i2cPresent(GRAPHIC_ADDRESS) &&
                 graphic.begin(SSD1306_SWITCHCAPVCC, GRAPHIC_ADDRESS, false, false);
  characterReady = character.begin(Wire, CHARACTER_ADDRESS);

  setupEncoder(volumeEncoder);
  setupEncoder(profileEncoder);
  keyboard.begin();
  consumer.begin();
  USB.productName("Blip Hackpad");
  USB.manufacturerName("Blip");
  USB.begin();
  reportDiagnostics();
  updateDisplays(true);
}

void loop() {
  scanMatrix();

  int8_t volumeStep = readEncoderRotation(volumeEncoder);
  if (volumeStep > 0) tapMedia(CONSUMER_CONTROL_VOLUME_INCREMENT, "Volume up");
  else if (volumeStep < 0) tapMedia(CONSUMER_CONTROL_VOLUME_DECREMENT, "Volume down");
  SwitchEvent volumeSwitch = readEncoderSwitch(volumeEncoder);
  if (volumeSwitch == SwitchEvent::RELEASED && !volumeEncoder.longPressHandled) {
    tapMedia(CONSUMER_CONTROL_MUTE, "Mute");
  }

  int8_t profileStep = readEncoderRotation(profileEncoder);
  if (profileStep != 0) selectProfile(profileStep);
  SwitchEvent profileSwitch = readEncoderSwitch(profileEncoder);
  if (profileSwitch == SwitchEvent::RELEASED && !profileEncoder.longPressHandled) {
    lastAction = String("Selected: ") + config.profiles[config.activeProfile].name;
    if (configDirty) {
      config.save();
      configDirty = false;
    }
  } else if (profileSwitch == SwitchEvent::LONG_PRESS) lastAction = "USB config ready";

  handleSerial();
  updateDisplays();
  delay(1);
}

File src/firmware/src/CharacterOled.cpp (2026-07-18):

#include "CharacterOled.h"

void CharacterOled::command(uint8_t value) {
  bus->beginTransmission(i2cAddress);
  bus->write(0x00);
  bus->write(value);
  if (bus->endTransmission() != 0) available = false;
  delayMicroseconds(40);
}

void CharacterOled::data(uint8_t value) {
  bus->beginTransmission(i2cAddress);
  bus->write(0x40);
  bus->write(value);
  if (bus->endTransmission() != 0) available = false;
}

bool CharacterOled::begin(TwoWire& wire, uint8_t address) {
  bus = &wire;
  i2cAddress = address;
  bus->beginTransmission(address);
  available = bus->endTransmission() == 0;
  if (!available) return false;

  delay(100);
  // US2066 initialization for 20x4 character OLED, I2C mode.
  struct InitStep { uint8_t value; bool isData; };
  const InitStep sequence[] = {
      {0x2A, false}, {0x71, false}, {0x00, true},  {0x28, false},
      {0x08, false}, {0x2A, false}, {0x79, false}, {0xD5, false},
      {0x70, false}, {0x78, false}, {0x09, false}, {0x06, false},
      {0x72, false}, {0x00, true},  {0x2A, false}, {0x79, false},
      {0xDA, false}, {0x10, false}, {0xDC, false}, {0x00, false},
      {0x81, false}, {0x7F, false}, {0xD9, false}, {0xF1, false},
      {0xDB, false}, {0x40, false}, {0x78, false}, {0x28, false},
      {0x01, false}, {0x80, false}, {0x0C, false}};
  for (const InitStep& step : sequence) {
    if (step.isData) data(step.value);
    else command(step.value);
    if (!available) return false;
    delay(2);
  }
  return true;
}

void CharacterOled::clear() {
  if (available) {
    command(0x01);
    delay(2);
  }
}

void CharacterOled::setCursor(uint8_t column, uint8_t row) {
  static const uint8_t offsets[] = {0x00, 0x20, 0x40, 0x60};
  if (available && row < 4 && column < 20) command(0x80 | (offsets[row] + column));
}

void CharacterOled::printPadded(uint8_t row, const String& text) {
  if (!available || row > 3) return;
  setCursor(0, row);
  for (uint8_t i = 0; i < 20; ++i) data(i < text.length() ? text[i] : ' ');
}

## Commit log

2026-07-17 Create PCB folder placeholder
2026-07-17 Replace README with full project overview, journal summary, and BOM
2026-07-17 Revise README for clarity and conciseness
    Updated project description and simplified the journey section. Adjusted BOM references and clarified folder contents.
2026-07-18 updated file structure
    [Hackpad_final_BOM.csv]
2026-07-27 Remove obsolete firmware and PCB documentation
2026-07-27 Establish Blip hardware baseline
    [Hackpad.kicad_pcb, Hackpad.kicad_sch]
2026-07-27 Apply minimal Blip PCB corrections
    [Hackpad.kicad_pcb, Hackpad.kicad_sch, Hackpad_final_BOM.csv]
2026-07-27 Build Blip hardware validation gate
    [Hackpad.kicad_pcb]
2026-07-28 Prove simulator-to-Agent tracer bullet (#5)
2026-07-29 Document Blip hardware BOM and validation status
    [Hackpad_final_BOM.csv]
2026-08-10 Add PCB Gerbers export
2026-08-10 Add submission BOM with purchase links
    [BOM.csv]
